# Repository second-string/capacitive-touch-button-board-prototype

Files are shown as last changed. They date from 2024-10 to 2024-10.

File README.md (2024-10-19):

# capacitive-touch-button-board-prototype

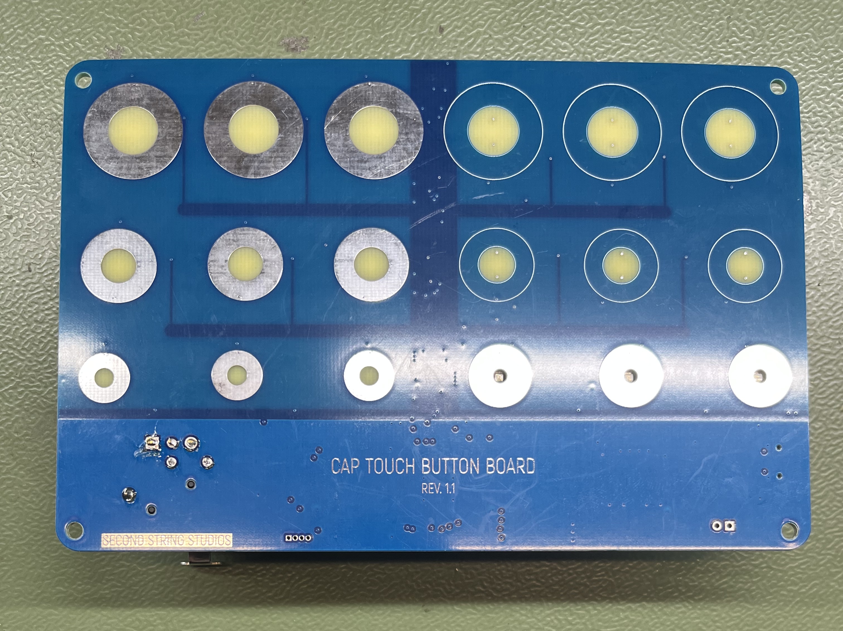
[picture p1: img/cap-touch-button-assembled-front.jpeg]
Version 1.1 of the capacitive touch button test board front

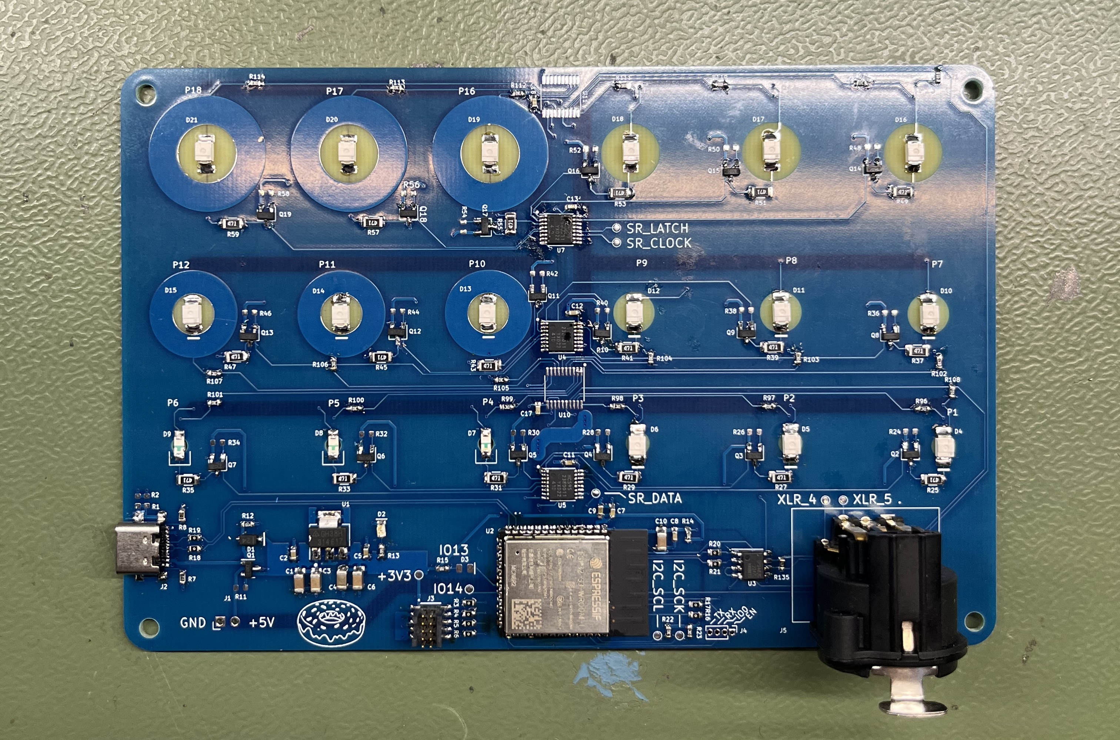
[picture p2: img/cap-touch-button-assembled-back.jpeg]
Version 1.1 of the capacitive touch button test board back


This repo contains two designs for prototype PCBs for testing different capacitive touch button styles and different reverse-mounted LED colors and styles. While version 1.1 was indeed fabbed, built, and works, these files are made public only for reference. **Do not expect to build these designs with no changes and have everything working for you**.

Version 1.0 is the full 6x6 version of the board. It all fabrication outputs were generated, but the board was never fabbed due to cost.
Version 1.1 is the same as 1.0 but with the top 3 rows of buttons removed to simplify the design physical size and part cost.   

There is a schematic PDF and PCB layer prints PDF in the version 1.1 directory if you do not have KiCad. Version 1.1 that was built also contains generated Excel and interactive boms in its main directory or the `bom/` directory.

Find the custom capacitive touch footprints in the `symbols_and_footprints/` directory of each hardware version.

There is test firmware for version 1.1 in `button-board_rev_1_1/bringup_firmware/`. **NOTE:** This firmware is sloppy, terribly written, inefficient, and everything is hardcoded. It is only included as a reference, do not think that this will work for you out of the box.

Videos of example behavior are in the `img/` directory.

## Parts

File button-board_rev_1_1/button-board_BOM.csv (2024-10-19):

Reference | Value | Footprint | Link | MPN | Menge
C1, C3, C6, C10 | 10uF | Capacitor_SMD:C_1206_3216Metric | https://www.digikey.de/en/products/detail/samsung-electro-mechanics/CL31B106KOHNNWE/3888763 | CL31B106KOHNNWE | 4
C2, C5, C9 | 1uF | Capacitor_SMD:C_0603_1608Metric | https://www.digikey.de/en/products/detail/samsung-electro-mechanics/CL10A105KA8NNNC/3886760 | CL10A105KA8NNNC | 3
C4 | 22uF | Capacitor_SMD:C_1206_3216Metric | https://www.digikey.de/en/products/detail/samsung-electro-mechanics/CL31A226MOCLNNC/3888386 | CL31A226MOCLNNC | 1
C7, C8, C11-C13, C17, C18 | 0.1uF | Capacitor_SMD:C_0603_1608Metric | https://www.digikey.de/en/products/detail/kyocera-avx/KGM15BR71H104KT/1600046 | KYOCERA AVX | 7
D1 | D | Diode_SMD:D_SOD-123F | https://www.digikey.de/en/products/detail/good-ark-semiconductor/FS24/18667767 | FS24 | 1
D2, D3 | LED | Diode_SMD:D_0805_2012Metric |  |  | 2
D4-D6, D10-D12, D16-D21 | LED | LED_SMD:LED_SunLED_XZ_Reverse_Mount |  |  | 12
D7-D9 | LED | LTST-C230K:LED_LTST-C230K |  |  | 3
D13-D15 | LED | LED_SMD:LED_SunLED_XZ_Reverse_Mount_Cut_Pads |  |  | 3
H1-H4 | MountingHole | MountingHole:MountingHole_3.2mm_M3 |  |  | 4
J1 | Screw_Terminal_01x02 | Connector_PinHeader_2.54mm:PinHeader_1x02_P2.54mm_Horizontal |  |  | 1
J2 | USB_C_Receptacle_USB2.0_EDITED | GSB1C41110SSHR:AMPHENOL_GSB1C41110SSHR | https://www.digikey.de/en/products/detail/amphenol-cs-commercial-products/GSB1C41110SSHR/21623839 | GSB1C41110SSHR | 1
J3 | FTSH-105-01-S-DV-TR | FTSH-105-01-S-DV-TR:SAMTEC_FTSH-105-01-S-DV-TR | https://www.digikey.de/en/products/detail/samtec-inc/FTSH-105-01-S-DV-TR/7432340 | FTSH-105-01-S-DV-TR | 1
J4 | Conn_01x04 | Connector_PinHeader_1.27mm:PinHeader_1x04_P1.27mm_Vertical |  |  | 1
J5 | XLR5_Ground | NC5FAH:NEUTRIK_NC5FAH | https://www.digikey.de/en/products/detail/amphenol-sine-systems-corp/AC5FAV-AU-B/10443110 | AC5FAV-AU-B | 1
P1-P3 | ~ | Button_Switch_SMD:Cap_Touch_Ring_Small |  |  | 3
P4-P6 | ~ | Button_Switch_SMD:Cap_Touch_Ring_Cutout |  |  | 3
P7-P9 | ~ | Button_Switch_SMD:Cap_Touch_Ring_Medium |  |  | 3
P10-P12 | ~ | Button_Switch_SMD:Cap_Touch_Ring_Medium_Bottom |  |  | 3
P13-P15 | ~ | Button_Switch_SMD:Cap_Touch_Ring_Large |  |  | 3
P16-P18 | ~ | Button_Switch_SMD:Cap_Touch_Ring_Large_Bottom |  |  | 3
Q1 | PMOS | Package_TO_SOT_SMD:SOT-23 | https://www.digikey.de/en/products/detail/good-ark-semiconductor/GSF2301/18667474 | GSF2301 | 1
Q2-Q19 | NMOS | Package_TO_SOT_SMD:TSOT-23 | https://www.digikey.de/en/products/detail/anbon-semiconductor-int-l-limited/AS2302/16708469 | AS2302 | 18
R1-R6, R11, R16-R21 | 0R | Resistor_SMD:R_0603_1608Metric |  |  | 13
R7, R8 | 5k1 | Resistor_SMD:R_0603_1608Metric | https://www.digikey.de/en/products/detail/yageo/RT0603DRD075K1L/1035586 | RT0603DRD075K1L | 2
R12 | 100k | Resistor_SMD:R_0603_1608Metric | https://www.digikey.de/en/products/detail/yageo/RC0603FR-0747KL/727253 | RC0603FR-0747KL | 1
R13, R15 | 3.3k-8k | Resistor_SMD:R_0603_1608Metric | https://www.digikey.de/en/products/detail/yageo/RC0603JR-076K8L/726813 | RC0603JR-076K8L | 2
R14, R22-R24, R26, R28, R30, R32, R34, R36, R38, R40, R42, R44, R46, R48, R50, R52, R54, R56, R58, R96-R107, R109-R114 | 10k | Resistor_SMD:R_0603_1608Metric | https://www.digikey.de/en/products/detail/yageo/RC0603FR-0710KL/726880 | RC0603FR-0710KL | 39
R25, R27, R29, R31, R33, R35, R37, R39, R41, R43, R45, R47, R49, R51, R53, R55, R57, R59 | 470R 1/2W | Resistor_SMD:R_1206_3216Metric | https://www.digikey.de/en/products/detail/panasonic-electronic-components/ERJ-P08J471V/525396 | ERJ-P08J471V | 18
R108, R121 | 47k | Resistor_SMD:R_0603_1608Metric | https://www.digikey.de/en/products/detail/yageo/RC0603FR-0747KL/727253 | RC0603FR-0747KL | 2
R135 | 120R | Resistor_SMD:R_0603_1608Metric | https://www.digikey.de/en/products/detail/stackpole-electronics-inc/RMCF0603FT120R/1761221 | RMCF0603FT120R | 1
TP1, TP2 | TestPoint | TestPoint:TestPoint_Pad_D1.0mm |  |  | 2
TP3 | 3V3 | TestPoint:TestPoint_Pad_D1.0mm |  |  | 1
TP4 | IO14 | TestPoint:TestPoint_Pad_D1.0mm |  |  | 1
TP5 | LATCH | TestPoint:TestPoint_Pad_D1.0mm |  |  | 1
TP6 | CLOCK | TestPoint:TestPoint_Pad_D1.0mm |  |  | 1
TP7 | DATA | TestPoint:TestPoint_Pad_D1.0mm |  |  | 1
TP8 | SCL | TestPoint:TestPoint_Pad_D1.0mm |  |  | 1
TP9 | SCK | TestPoint:TestPoint_Pad_D1.0mm |  |  | 1
U1 | AZ1117CH2-3.3 | Package_TO_SOT_SMD:SOT-223 | https://www.digikey.de/en/products/detail/diodes-incorporated/AZ1117CH2-3-3TRG1/7352815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 | AZ1117CH2-3.3TRG1 | 1
U2 | ESP32-S3-WROOM-1 | PCM_Espressif:ESP32-S3-WROOM-1 | https://www.digikey.de/en/products/detail/espressif-systems/ESP32-S3-WROOM-1-N8R2/15200058 | ESP32-S3-WROOM-1-N8R2 | 1
U3 | SP3485CN | Package_SO:SOIC-8_3.9x4.9mm_P1.27mm | https://www.digikey.de/en/products/detail/maxlinear-inc/SP3485CN-L/2411076 | SP3485CN-L | 1
U4, U5, U7 | 74HC595 | Package_SO:TSSOP-16_4.4x5mm_P0.65mm | https://www.digikey.de/en/products/detail/nexperia-usa-inc/74HC595PW-118/946653 | 74HC595PW,118 | 3
U10, U11 | AT42QT2120-SU | Package_SO:TSSOP-20_4.4x6.5mm_P0.65mm | https://www.digikey.de/en/products/detail/microchip-technology/AT42QT2120-SU/3678689 | AT42QT2120-SU | 2

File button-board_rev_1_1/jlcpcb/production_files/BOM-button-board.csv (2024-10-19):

Comment | Designator | Footprint | LCSC
XLR5_Ground | J5 | NEUTRIK_NC5FAH
LED | D15 | LED_SunLED_XZ_Reverse_Mount_Cut_Pads
LED | D14 | LED_SunLED_XZ_Reverse_Mount_Cut_Pads
LED | D13 | LED_SunLED_XZ_Reverse_Mount_Cut_Pads
LED | D12 | LED_SunLED_XZ_Reverse_Mount
LED | D11 | LED_SunLED_XZ_Reverse_Mount
LED | D10 | LED_SunLED_XZ_Reverse_Mount
~ | P17 | Cap_Touch_Ring_Large_Bottom
~ | P16 | Cap_Touch_Ring_Large_Bottom
~ | P9 | Cap_Touch_Ring_Medium
~ | P13 | Cap_Touch_Ring_Large
~ | P7 | Cap_Touch_Ring_Medium
~ | P5 | Cap_Touch_Ring_Cutout
MountingHole | H1 | MountingHole_3.2mm_M3
MountingHole | H2 | MountingHole_3.2mm_M3
~ | P11 | Cap_Touch_Ring_Medium_Bottom
~ | P14 | Cap_Touch_Ring_Large
~ | P12 | Cap_Touch_Ring_Medium_Bottom
MountingHole | H3 | MountingHole_3.2mm_M3
~ | P6 | Cap_Touch_Ring_Cutout
~ | P1 | Cap_Touch_Ring_Small
~ | P15 | Cap_Touch_Ring_Large
~ | P3 | Cap_Touch_Ring_Small
~ | P10 | Cap_Touch_Ring_Medium_Bottom
~ | P4 | Cap_Touch_Ring_Cutout
MountingHole | H4 | MountingHole_3.2mm_M3
~ | P2 | Cap_Touch_Ring_Small
~ | P8 | Cap_Touch_Ring_Medium
~ | P18 | Cap_Touch_Ring_Large_Bottom
0R | R16 | R_0603_1608Metric
470R 1/2W | R59 | R_1206_3216Metric
NMOS | Q8 | TSOT-23
1uF | C5 | C_0603_1608Metric
470R 1/2W | R25 | R_1206_3216Metric
SCL | TP8 | TestPoint_Pad_D1.0mm
10k | R113 | R_0603_1608Metric
470R 1/2W | R45 | R_1206_3216Metric
10uF | C10 | C_1206_3216Metric
470R 1/2W | R35 | R_1206_3216Metric
ESP32-S3-WROOM-1 | U2 | ESP32-S3-WROOM-1
NMOS | Q11 | TSOT-23
470R 1/2W | R41 | R_1206_3216Metric
47k | R108 | R_0603_1608Metric
R | R4 | R_0603_1608Metric
470R 1/2W | R57 | R_1206_3216Metric
100k | R12 | R_0603_1608Metric
NMOS | Q18 | TSOT-23
0.1uF | C17 | C_0603_1608Metric
AT42QT2120-SU | U11 | TSSOP-20_4.4x6.5mm_P0.65mm
AZ1117CH2-3.3 | U1 | SOT-223
10k | R112 | R_0603_1608Metric
NMOS | Q2 | TSOT-23
0.1uF | C8 | C_0603_1608Metric
0R | R18 | R_0603_1608Metric
74HC595 | U4 | TSSOP-16_4.4x5mm_P0.65mm
TestPoint | TP1 | TestPoint_Pad_D1.0mm
CLOCK | TP6 | TestPoint_Pad_D1.0mm
470R 1/2W | R37 | R_1206_3216Metric
0.1uF | C13 | C_0603_1608Metric
47k | R121 | R_0603_1608Metric
NMOS | Q9 | TSOT-23
R | R3 | R_0603_1608Metric
0R | R20 | R_0603_1608Metric
74HC595 | U7 | TSSOP-16_4.4x5mm_P0.65mm
SP3485CN | U3 | SOIC-8_3.9x4.9mm_P1.27mm
10k | R97 | R_0603_1608Metric
470R 1/2W | R39 | R_1206_3216Metric
470R 1/2W | R49 | R_1206_3216Metric
SCK | TP9 | TestPoint_Pad_D1.0mm
NMOS | Q19 | TSOT-23
470R 1/2W | R31 | R_1206_3216Metric
10k | R100 | R_0603_1608Metric
R | R5 | R_0603_1608Metric
LED | D4 | LED_SunLED_XZ_Reverse_Mount
10k | R105 | R_0603_1608Metric
3.3k-8k | R15 | R_0603_1608Metric
470R 1/2W | R55 | R_1206_3216Metric
470R 1/2W | R51 | R_1206_3216Metric
10k | R107 | R_0603_1608Metric
0R | R19 | R_0603_1608Metric
10k | R106 | R_0603_1608Metric
470R 1/2W | R43 | R_1206_3216Metric
IO14 | TP4 | TestPoint_Pad_D1.0mm
LATCH | TP5 | TestPoint_Pad_D1.0mm
TestPoint | TP2 | TestPoint_Pad_D1.0mm
NMOS | Q7 | TSOT-23
1uF | C9 | C_0603_1608Metric
120R | R135 | R_0603_1608Metric
22uF | C4 | C_1206_3216Metric
0.1uF | C11 | C_0603_1608Metric
10k | R101 | R_0603_1608Metric
PMOS | Q1 | SOT-23
10k | R110 | R_0603_1608Metric
LED | D19 | LED_SunLED_XZ_Reverse_Mount
0.1uF | C7 | C_0603_1608Metric
FTSH-105-01-S-DV-TR | J3 | SAMTEC_FTSH-105-01-S-DV-TR
5k1 | R7 | R_0603_1608Metric
10k | R111 | R_0603_1608Metric
10k | R102 | R_0603_1608Metric
0R | R17 | R_0603_1608Metric
NMOS | Q4 | TSOT-23
470R 1/2W | R27 | R_1206_3216Metric
DATA | TP7 | TestPoint_Pad_D1.0mm
NMOS | Q6 | TSOT-23
10k | R14 | R_0603_1608Metric
NMOS | Q12 | TSOT-23
NMOS | Q13 | TSOT-23
10k | R103 | R_0603_1608Metric
LED | D7 | LED_LTST-C230K
AT42QT2120-SU | U10 | TSSOP-20_4.4x6.5mm_P0.65mm
10k | R99 | R_0603_1608Metric
3V3 | TP3 | TestPoint_Pad_D1.0mm
LED | D21 | LED_SunLED_XZ_Reverse_Mount
LED | D18 | LED_SunLED_XZ_Reverse_Mount
1uF | C2 | C_0603_1608Metric
LED | D20 | LED_SunLED_XZ_Reverse_Mount
NMOS | Q15 | TSOT-23
LED | D3 | D_0805_2012Metric
470R 1/2W | R47 | R_1206_3216Metric
470R 1/2W | R53 | R_1206_3216Metric
10k | R114 | R_0603_1608Metric
10k | R22 | R_0603_1608Metric
10k | R104 | R_0603_1608Metric
10uF | C3 | C_1206_3216Metric
0.1uF | C18 | C_0603_1608Metric
10k | R23 | R_0603_1608Metric
0R | R21 | R_0603_1608Metric
10uF | C1 | C_1206_3216Metric
3.3k-8k | R13 | R_0603_1608Metric
LED | D9 | LED_LTST-C230K
NMOS | Q17 | TSOT-23
LED | D17 | LED_SunLED_XZ_Reverse_Mount
NMOS | Q14 | TSOT-23
USB_C_Receptacle_USB2.0_EDITED | J2 | AMPHENOL_GSB1C41110SSHR
10uF | C6 | C_1206_3216Metric
74HC595 | U5 | TSSOP-16_4.4x5mm_P0.65mm
Screw_Terminal_01x02 | J1 | PinHeader_1x02_P2.54mm_Horizontal
NMOS | Q10 | TSOT-23
LED | D2 | D_0805_2012Metric
NMOS | Q3 | TSOT-23
470R 1/2W | R33 | R_1206_3216Metric
10k | R109 | R_0603_1608Metric
R | R6 | R_0603_1608Metric
LED | D8 | LED_LTST-C230K
10k | R98 | R_0603_1608Metric
NMOS | Q5 | TSOT-23
D | D1 | D_SOD-123F
NMOS | Q16 | TSOT-23
LED | D6 | LED_SunLED_XZ_Reverse_Mount
470R 1/2W | R29 | R_1206_3216Metric
10k | R96 | R_0603_1608Metric
0.1uF | C12 | C_0603_1608Metric
LED | D5 | LED_SunLED_XZ_Reverse_Mount
5k1 | R8 | R_0603_1608Metric
Conn_01x04 | J4 | PinHeader_1x04_P1.27mm_Vertical
LED | D16 | LED_SunLED_XZ_Reverse_Mount

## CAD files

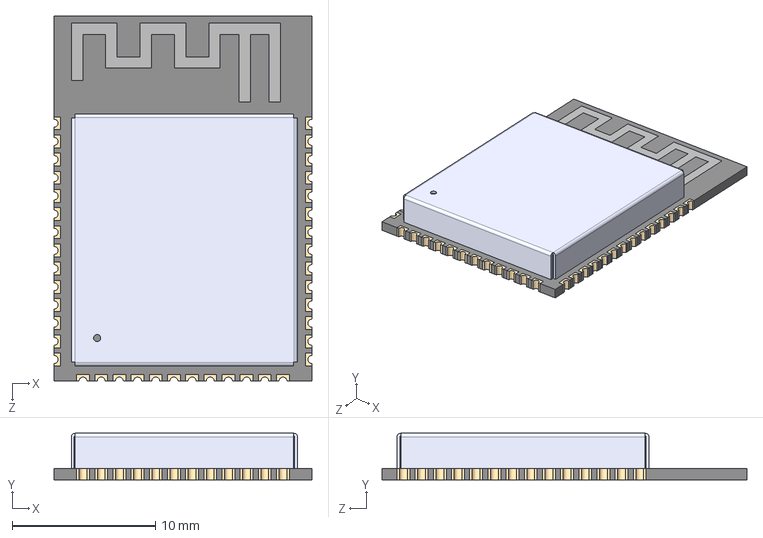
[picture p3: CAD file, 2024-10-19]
button-board_rev_1_1/symbols and footprints/ESP32-WROOM-S3/ESP32S3WROOM1N16R2.STEP
18.0 x 3.25 x 25.5 mm

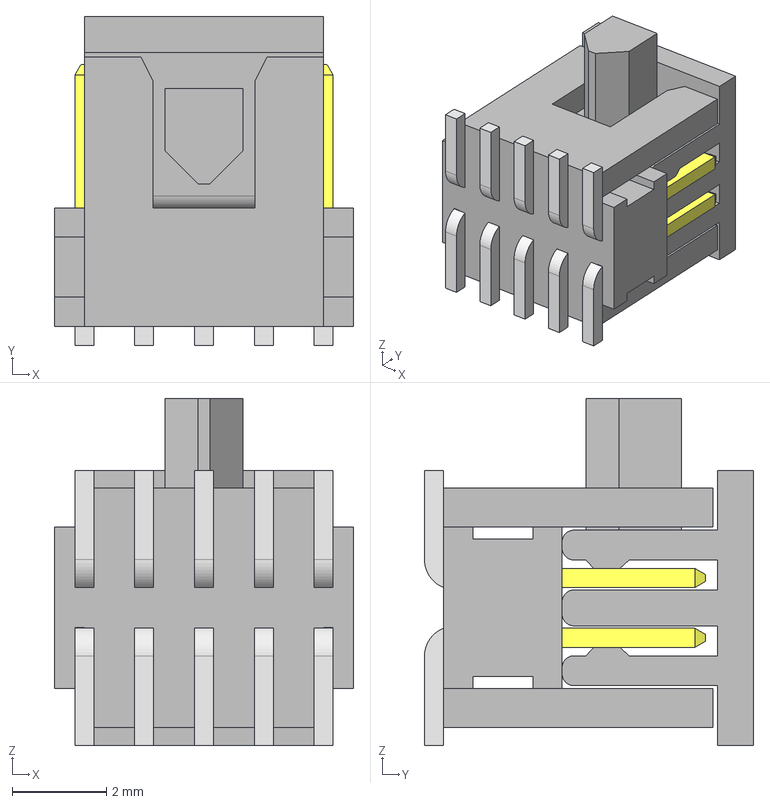
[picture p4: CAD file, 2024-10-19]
button-board_rev_1_1/symbols and footprints/FTSH-105-01-S-DV-TR/FTSH-105-01-S-DV-TR.step
6.35 x 6.98 x 7.37 mm
FTSH-105-01-S-DV-K-P-TR_body
FTSH-105-01-S-DV-K-P-TR_pins1
FTSH-105-01-S-DV-K-P-TR_pins2
FTSH-105-01-S-DV-K-P-TR_pp_pad

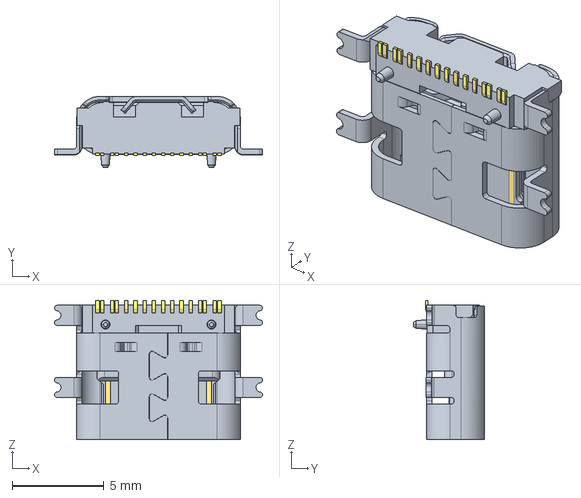
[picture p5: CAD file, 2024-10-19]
button-board_rev_1_1/symbols and footprints/GSB1C41110SSHR/GSB1C41110SSHR.step
11.3 x 3.89 x 7.60 mm

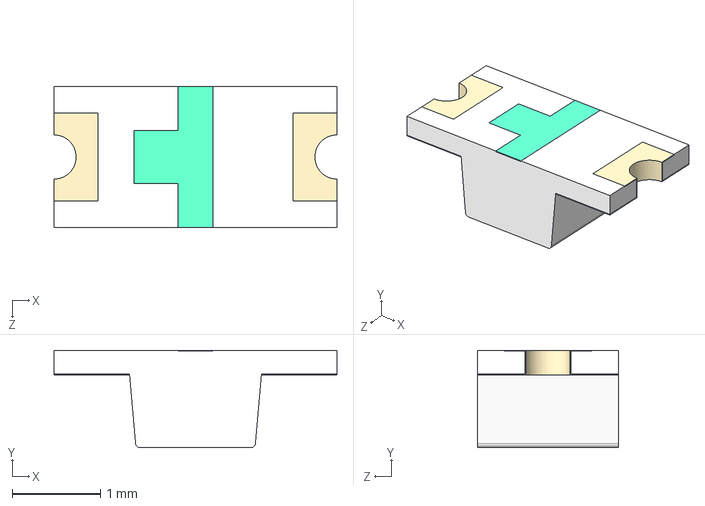
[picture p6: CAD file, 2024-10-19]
button-board_rev_1_1/symbols and footprints/LTST-C230K/LTST-C230K.step
3.20 x 1.10 x 1.60 mm

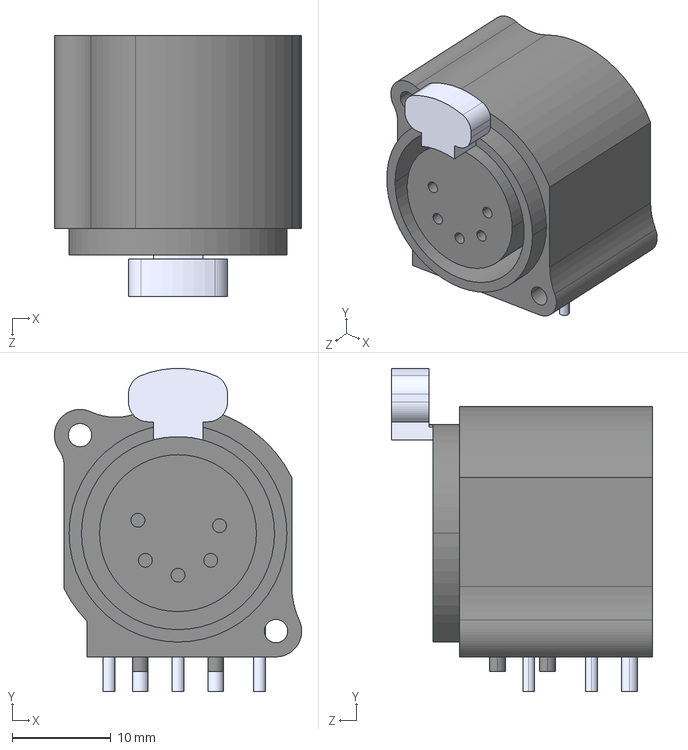
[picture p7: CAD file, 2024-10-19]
button-board_rev_1_1/symbols and footprints/NC5FAH/NC5FAH.step
25.0 x 32.6 x 26.4 mm

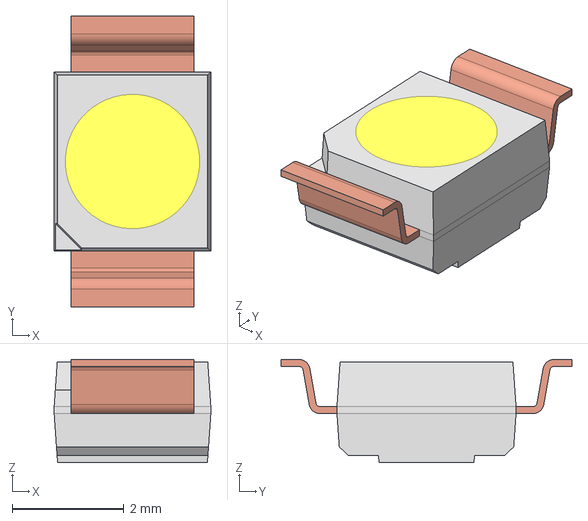
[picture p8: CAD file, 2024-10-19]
button-board_rev_1_1/symbols and footprints/XZxx45S/80472LED_SMD_PLCC-2_reverse_gullwing.stp
2.80 x 5.20 x 1.84 mm

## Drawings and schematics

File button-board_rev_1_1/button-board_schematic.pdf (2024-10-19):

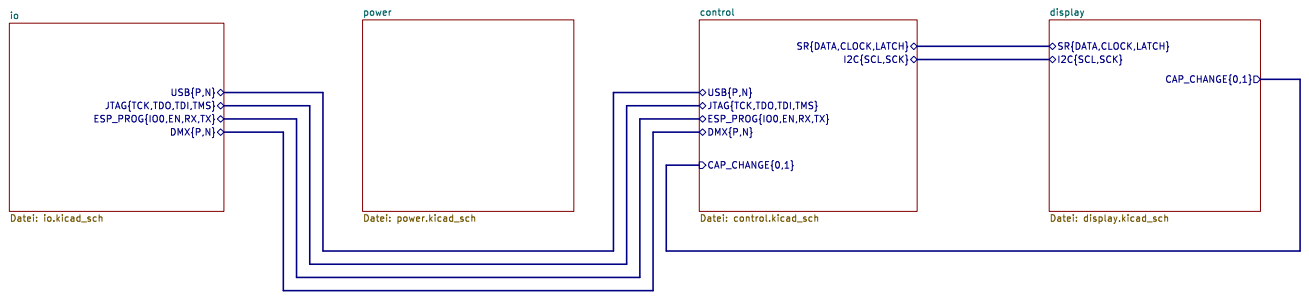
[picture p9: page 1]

SR{DATA,CLOCK,LATCH}

I2C{SCL,SCK}

USB{P,N}
JTAG{TCK,TDO,TDI,TMS}
ESP_PROG{IO0,EN,RX,TX}
DMX{P,N}

Id: 1/9 Title: File: button-board.kicad_sch Sheet: /

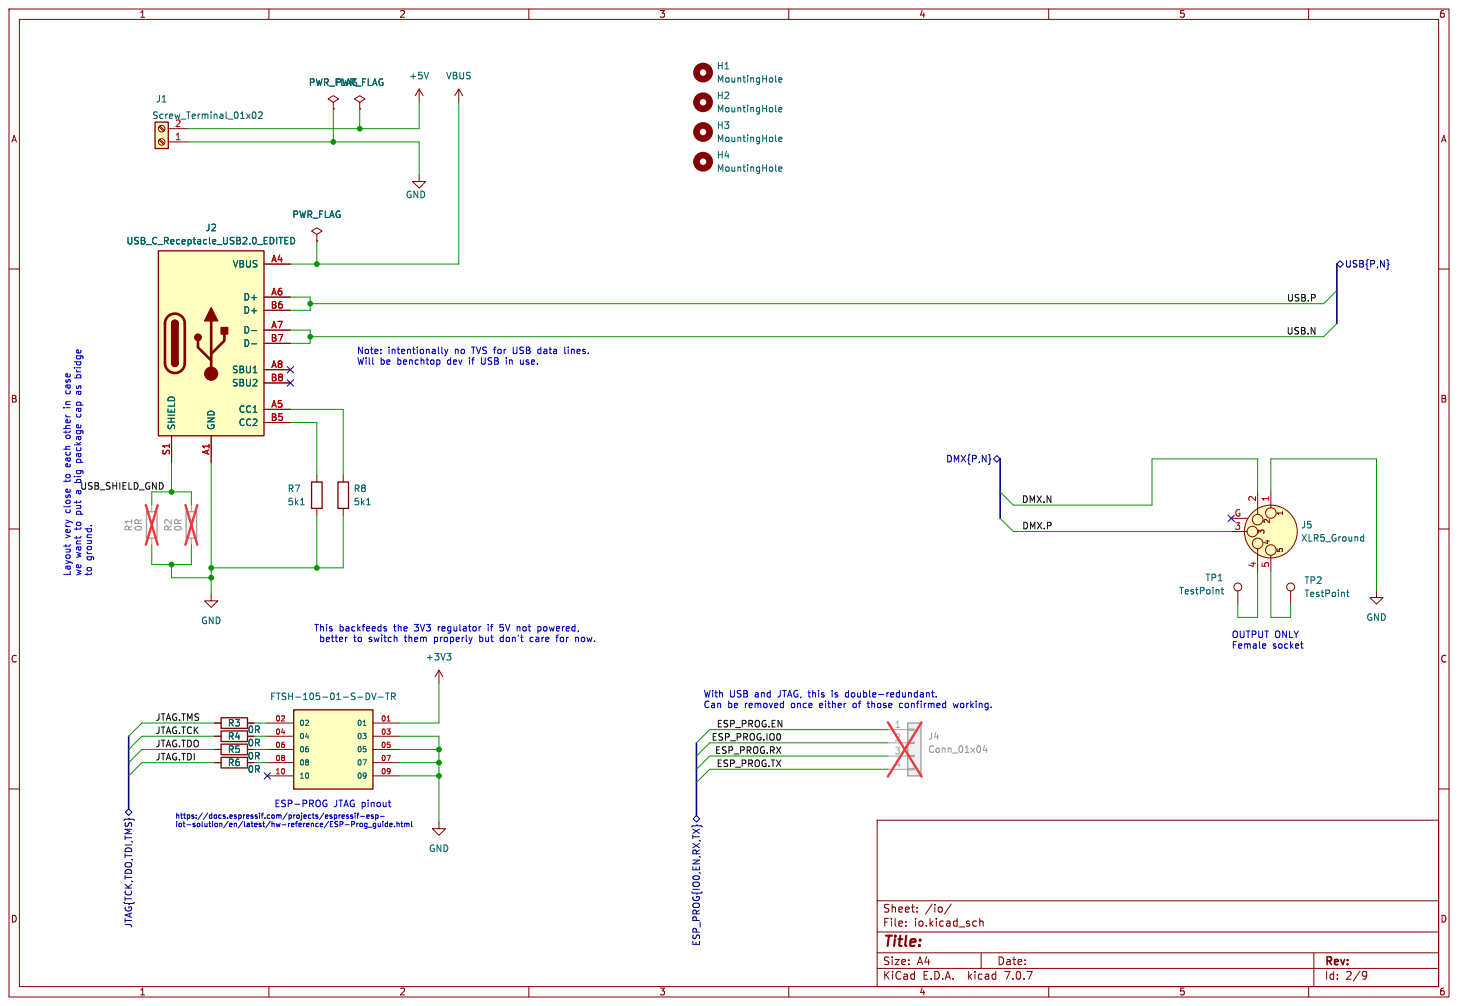
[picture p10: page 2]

USB{P,N} ESP_PROG{IO0,EN,RX,TX}

Id: 2/9 Title: File: io.kicad_sch Sheet: /io/

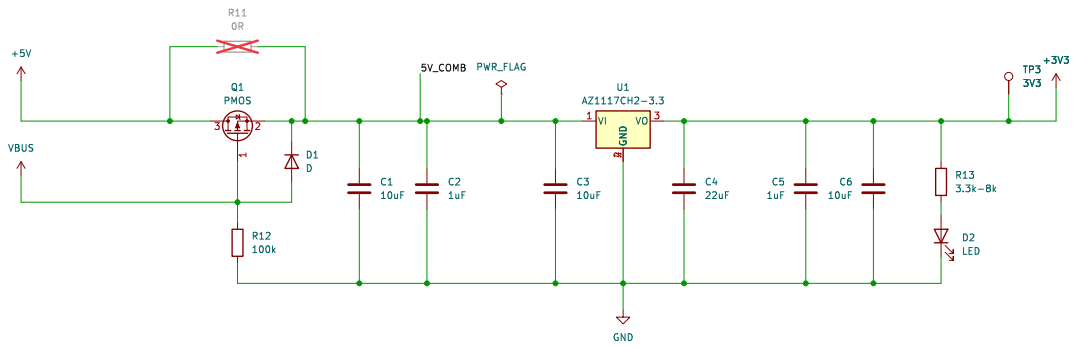
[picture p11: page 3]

Id: 3/9 Title: File: power.kicad_sch Sheet: /power/

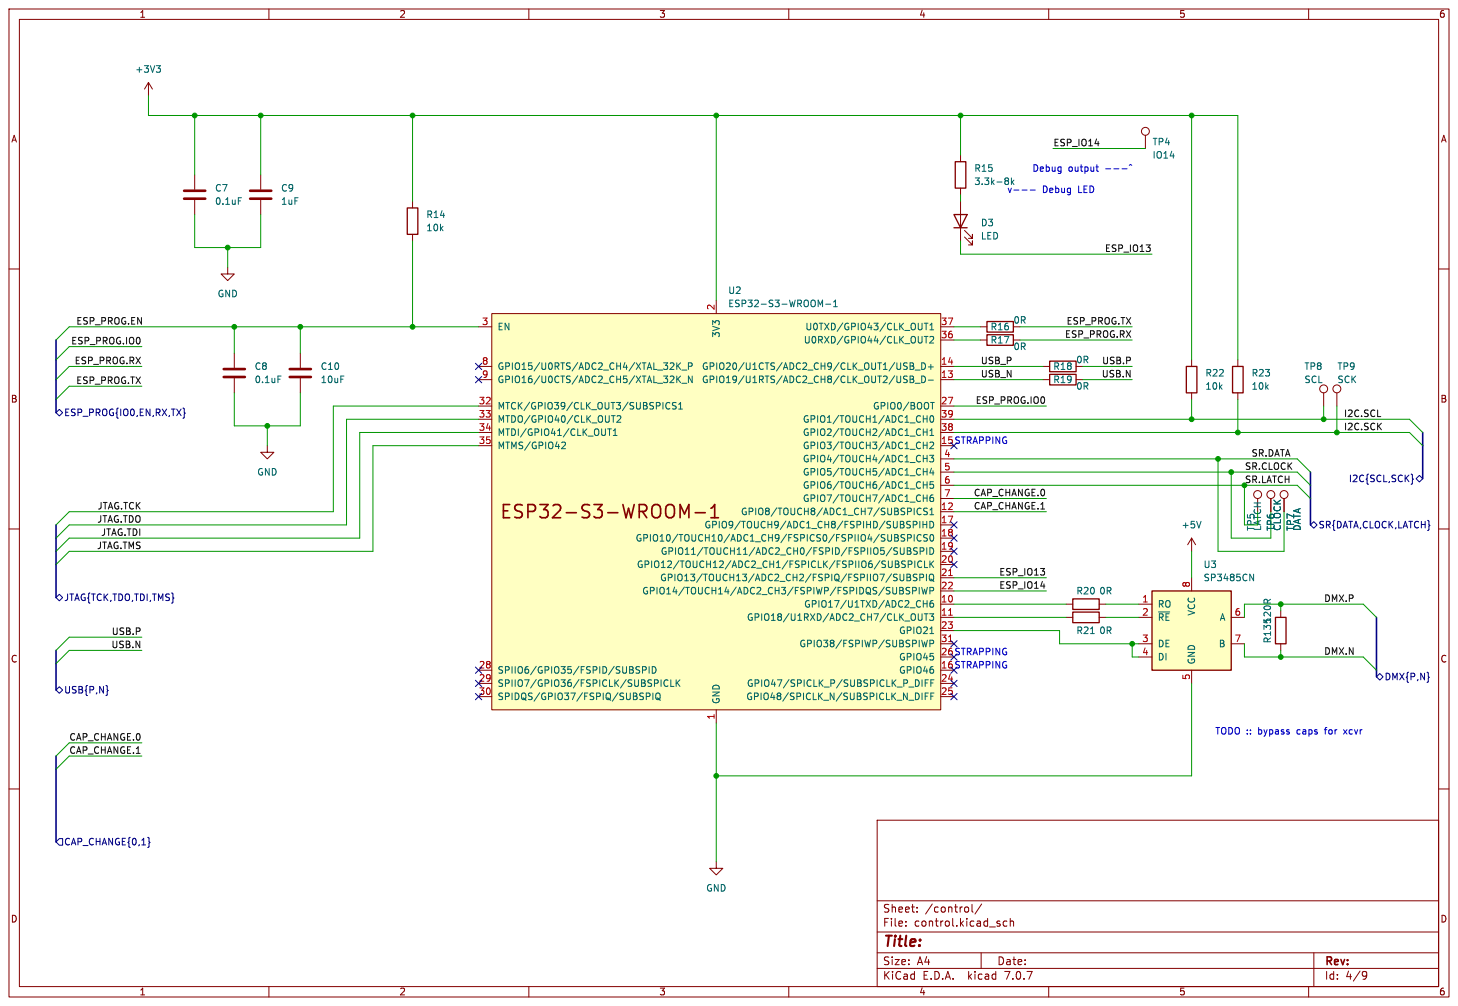
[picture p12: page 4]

2 GPIO12/TOUCH12/ADC2_CH1/FSPICLK/FSPIIO6/SUBSPICLK 20 GPIO13/TOUCH13/ADC2_CH2/FSPIQ/FSPIIO7/SUBSPIQ 21 GPIO14/TOUCH14/ADC2_CH3/FSPIWP/FSPIDQS/SUBSPIWP 22 GPIO21 23 GPIO47/SPICLK_P/SUBSPICLK_P_DIFF 24 GPIO48/SPICLK_N/SUBSPICLK_N_DIFF 25 GPIO45 26 GPIO0/BOOT 27 SPIIO6/GPIO35/FSPID/SUBSPID 28 SPIIO7/GPIO36/FSPICLK/SUBSPICLK 29 EN 3 SPIDQS/GPIO37/FSPIQ/SUBSPIQ 30 GPIO38/FSPIWP/SUBSPIWP 31 MTCK/GPIO39/CLK_OUT3/SUBSPICS1 32 MTDO/GPIO40/CLK_OUT2 33 MTDI/GPIO41/CLK_OUT1 34 MTMS/GPIO42 35 U0RXD/GPIO44/CLK_OUT2 36 U0TXD/GPIO43/CLK_OUT1 37 GPIO2/TOUCH2/ADC1_CH1 38 GPIO1/TOUCH1/ADC1_CH0 39 GPIO4/TOUCH4/ADC1_CH3 4 GPIO5/TOUCH5/ADC1_CH4 5 GPIO6/TOUCH6/ADC1_CH5 6 GPIO7/TOUCH7/ADC1_CH6 7 GPIO15/U0RTS/ADC2_CH4/XTAL_32K_P 8 GPIO16/U0CTS/ADC2_CH5/XTAL_32K_N 9 U2ESP32-S3-WROOM-1 R15

1 GPIO17/U1TXD/ADC2_CH6 10 GPIO18/U1RXD/ADC2_CH7/CLK_OUT3 11 GPIO8/TOUCH8/ADC1_CH7/SUBSPICS1 12 GPIO19/U1RTS/ADC2_CH8/CLK_OUT2/USB_D- 13 GPIO20/U1CTS/ADC2_CH9/CLK_OUT1/USB_D+ 14 GPIO3/TOUCH3/ADC1_CH2 15 GPIO46 16 GPIO9/TOUCH9/ADC1_CH8/FSPIHD/SUBSPIHD 17 GPIO10/TOUCH10/ADC1_CH9/FSPICS0/FSPIIO4/SUBSPICS0 18 GPIO11/TOUCH11/ADC2_CH0/FSPID/FSPIIO5/SUBSPID 19 3V3

TODO :: bypass caps for xcvr STRAPPING

SR{DATA,CLOCK,LATCH}

JTAG{TCK,TDO,TDI,TMS}

Id: 4/9 Title: File: control.kicad_sch Sheet: /control/

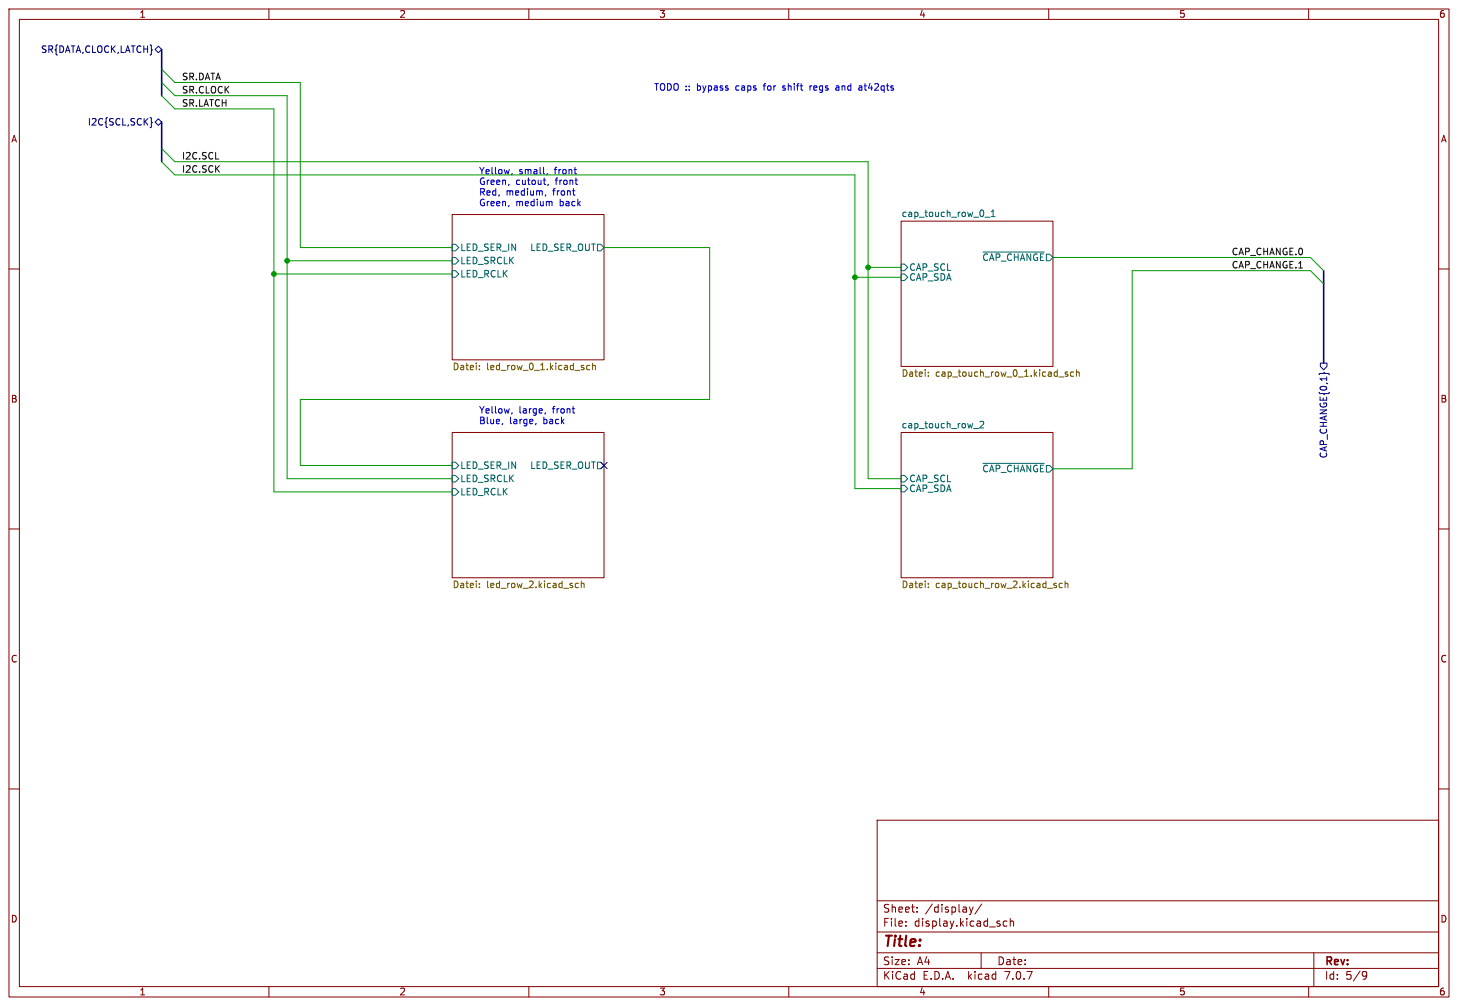
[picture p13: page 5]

TODO :: bypass caps for shift regs and at42qts Yellow, large, front Blue, large, back Yellow, small, front Green, cutout, front Red, medium, front Green, medium back

Id: 5/9 Title: File: display.kicad_sch Sheet: /display/

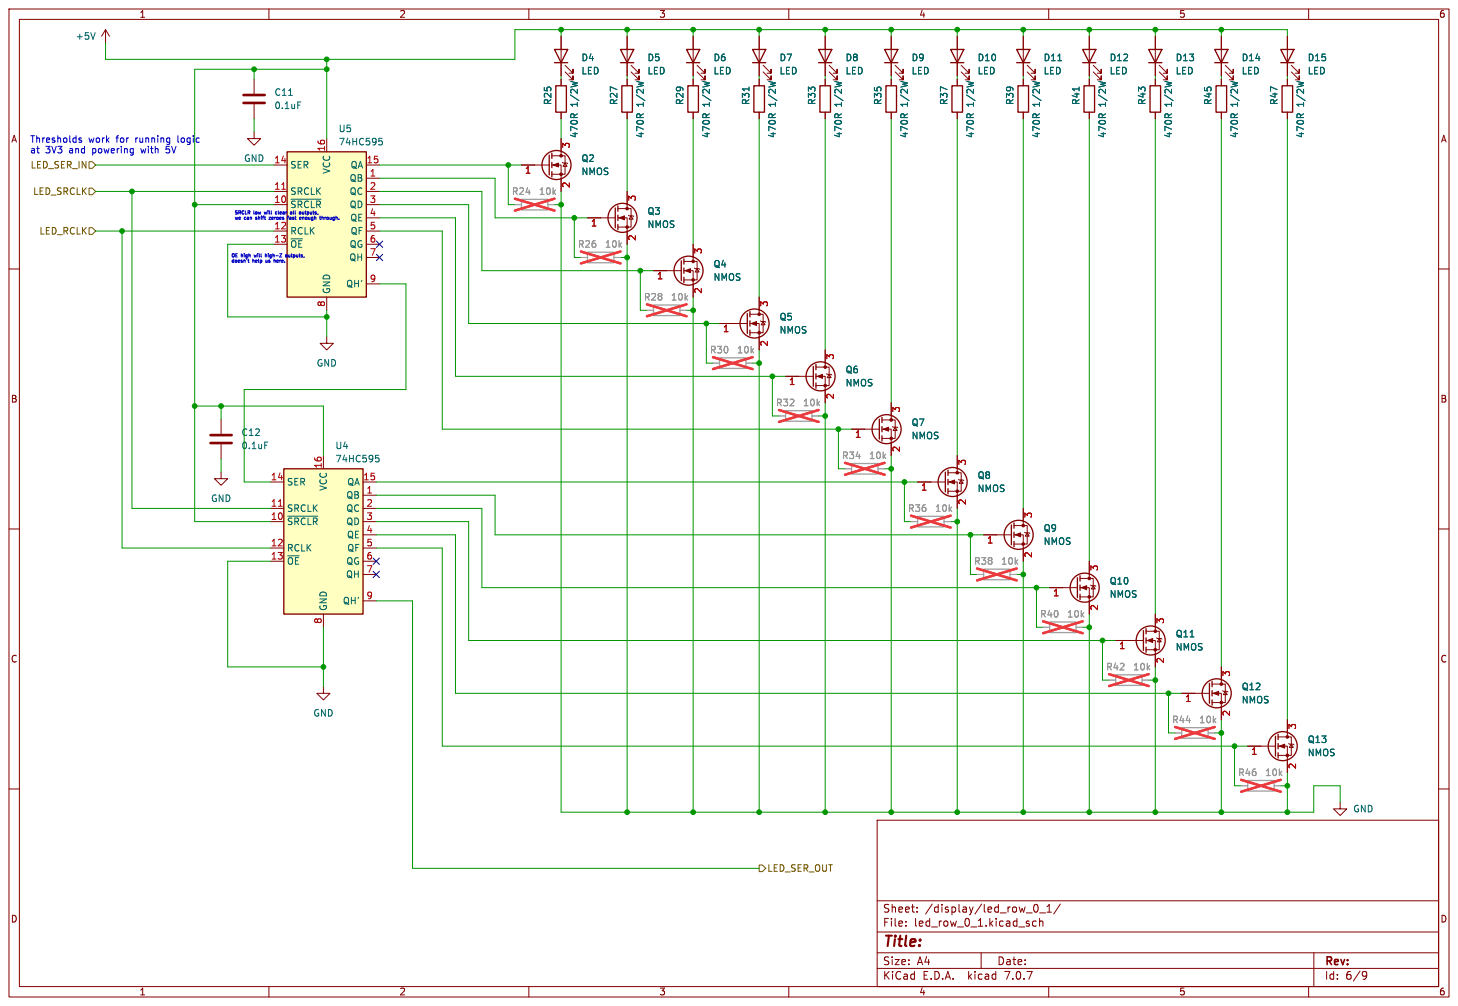
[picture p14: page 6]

Id: 6/9 Title: File: led_row_0_1.kicad_sch Sheet: /display/led_row_0_1/ R38 10k

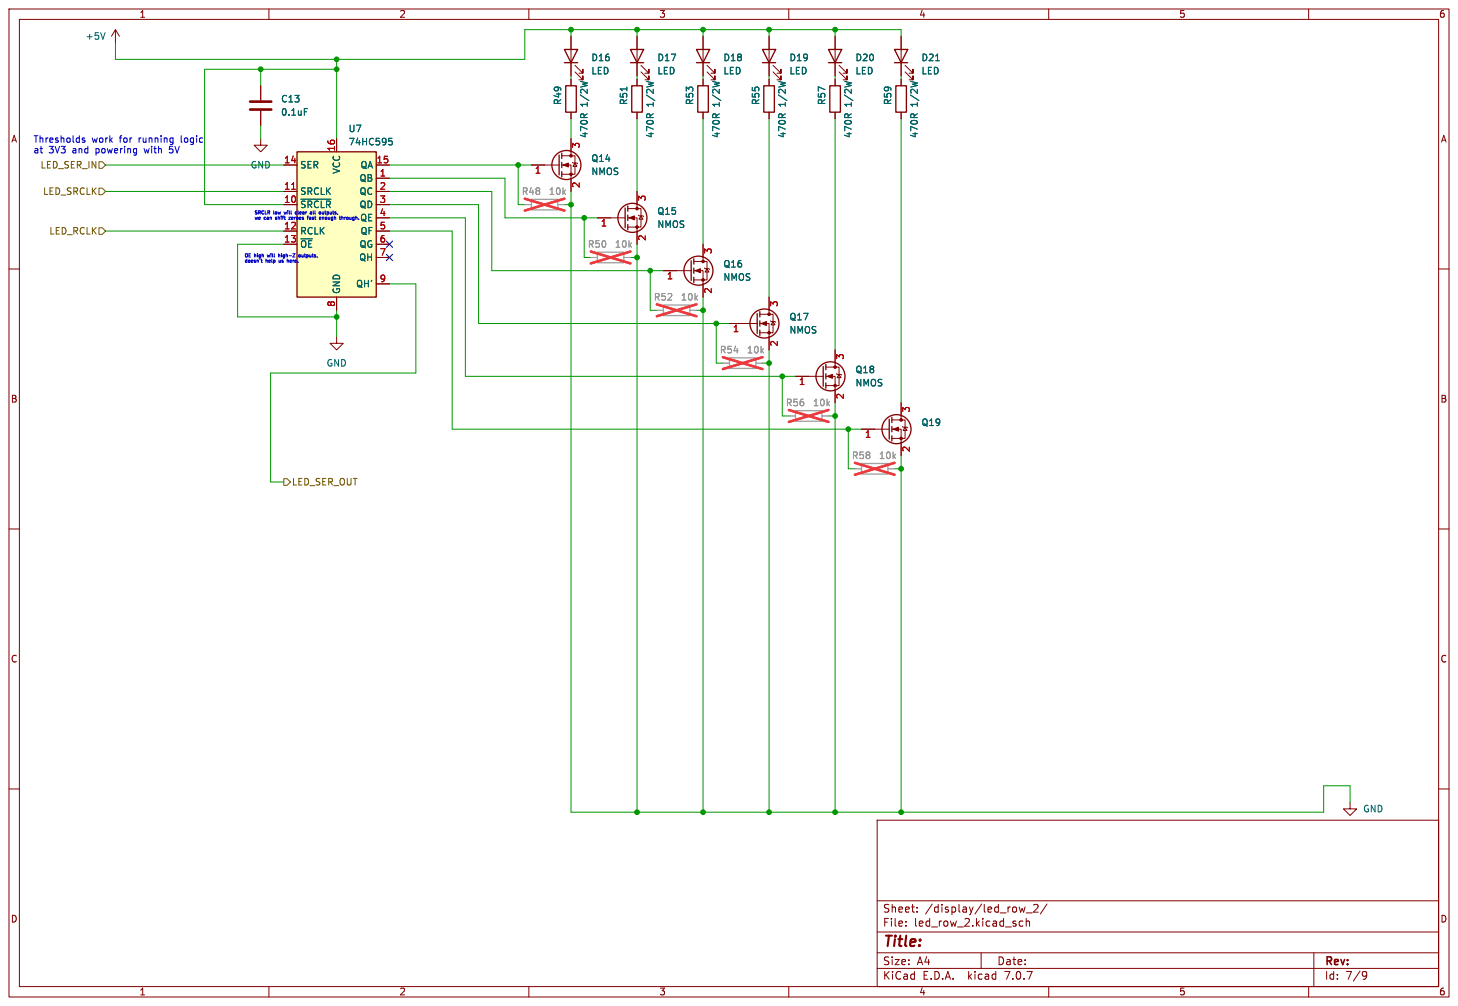
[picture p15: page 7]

Id: 7/9 Title: File: led_row_2.kicad_sch Sheet: /display/led_row_2/

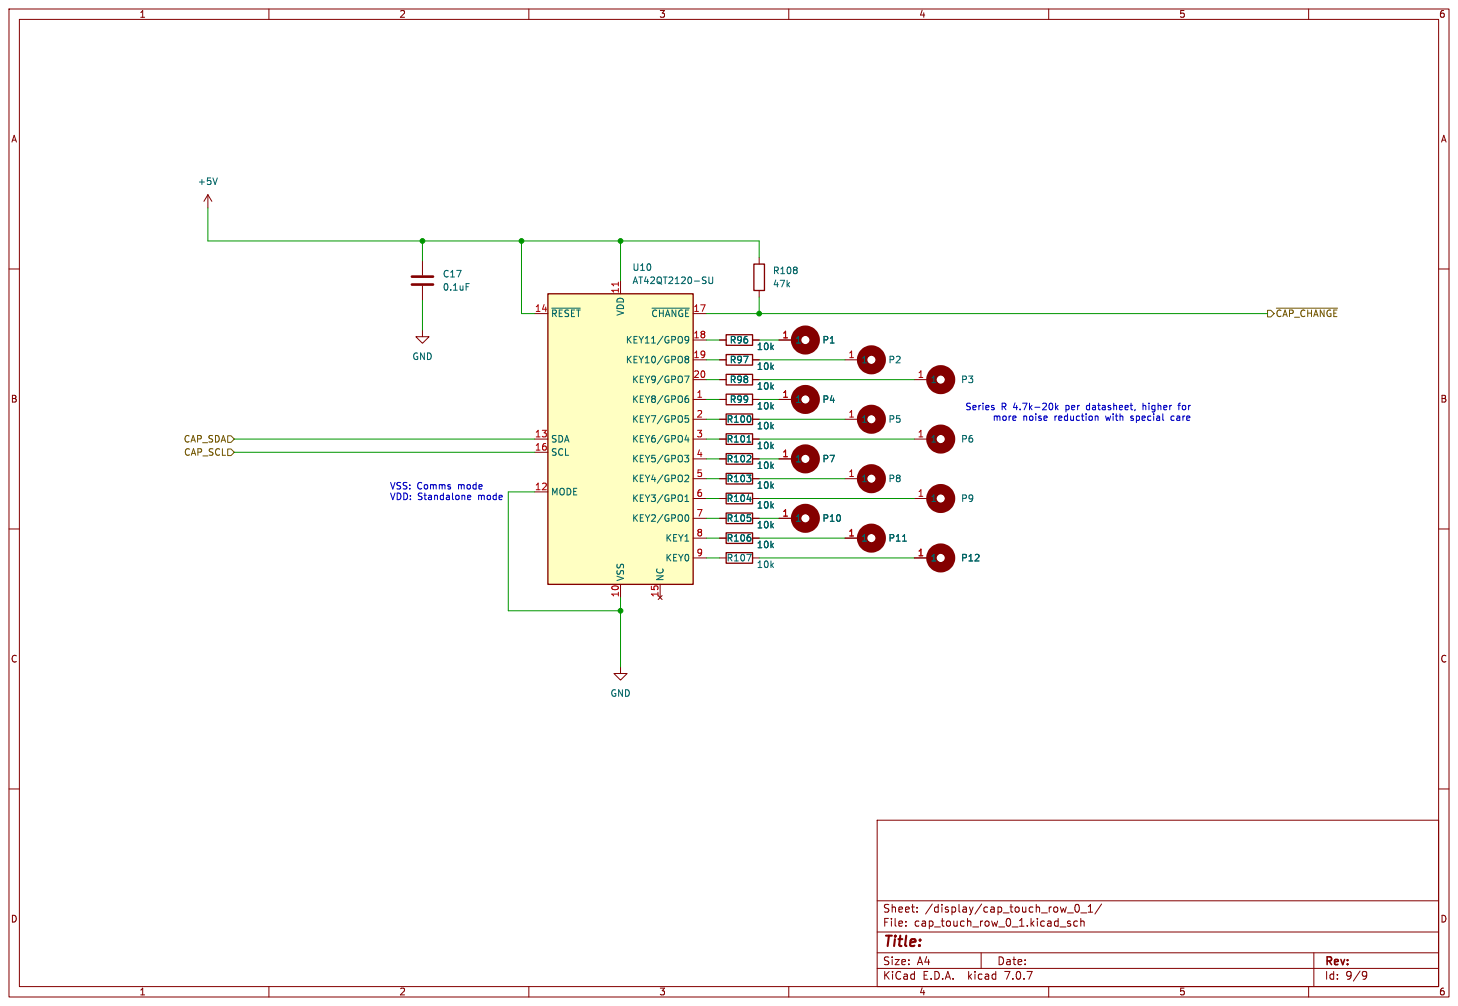
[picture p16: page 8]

Id: 9/9 Title: File: cap_touch_row_0_1.kicad_sch Sheet: /display/cap_touch_row_0_1/ GND

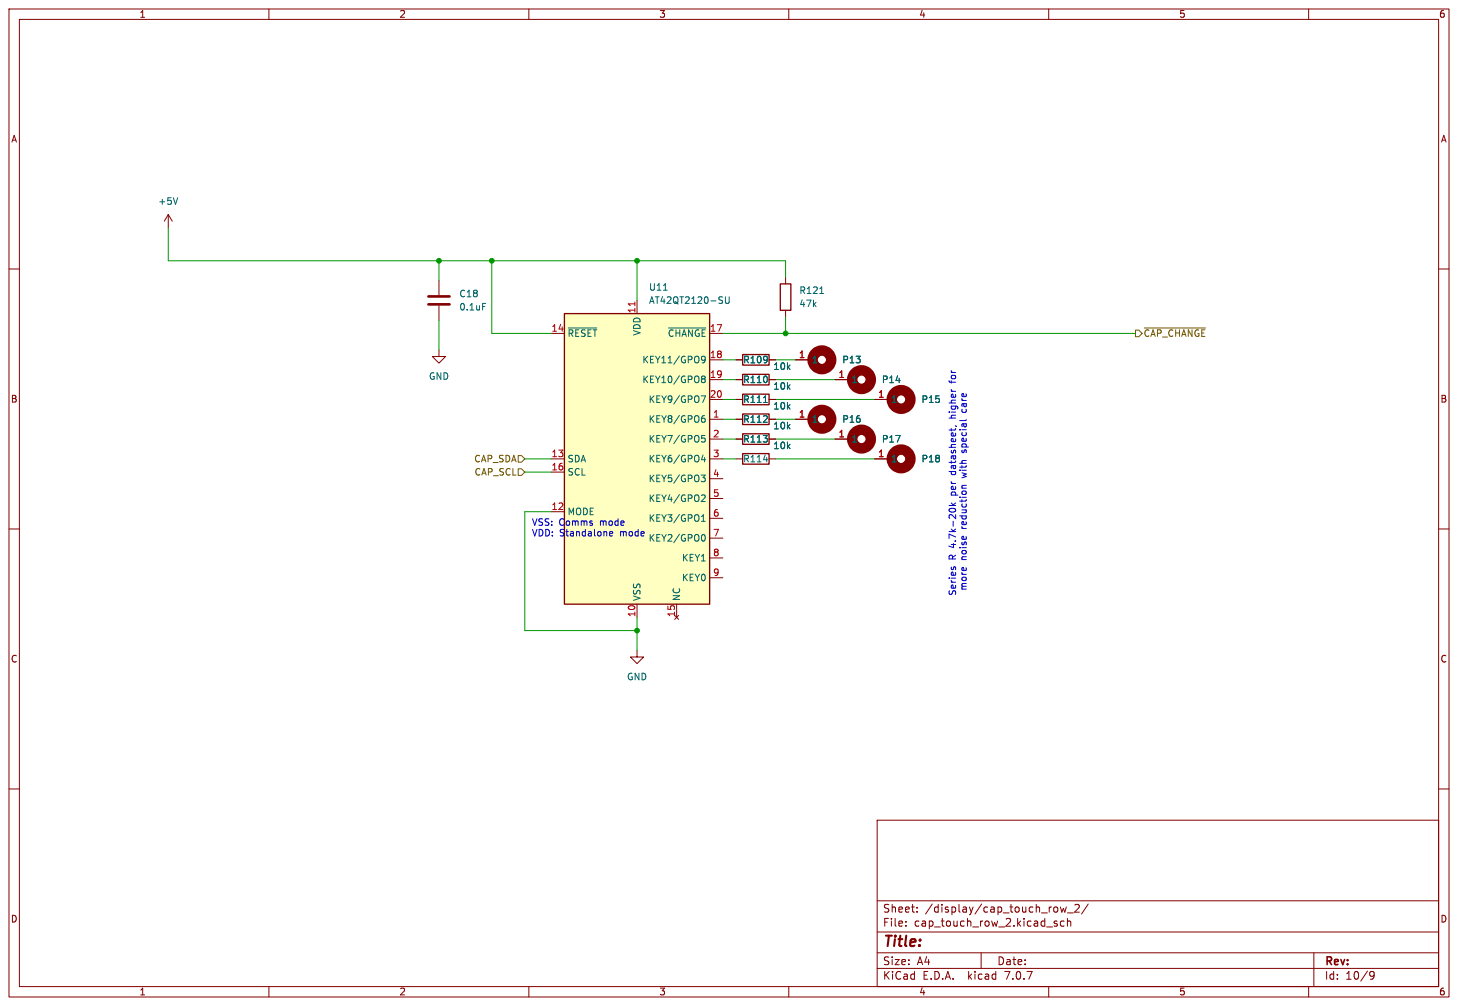
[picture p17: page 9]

Id: 10/9 Title: File: cap_touch_row_2.kicad_sch Sheet: /display/cap_touch_row_2/

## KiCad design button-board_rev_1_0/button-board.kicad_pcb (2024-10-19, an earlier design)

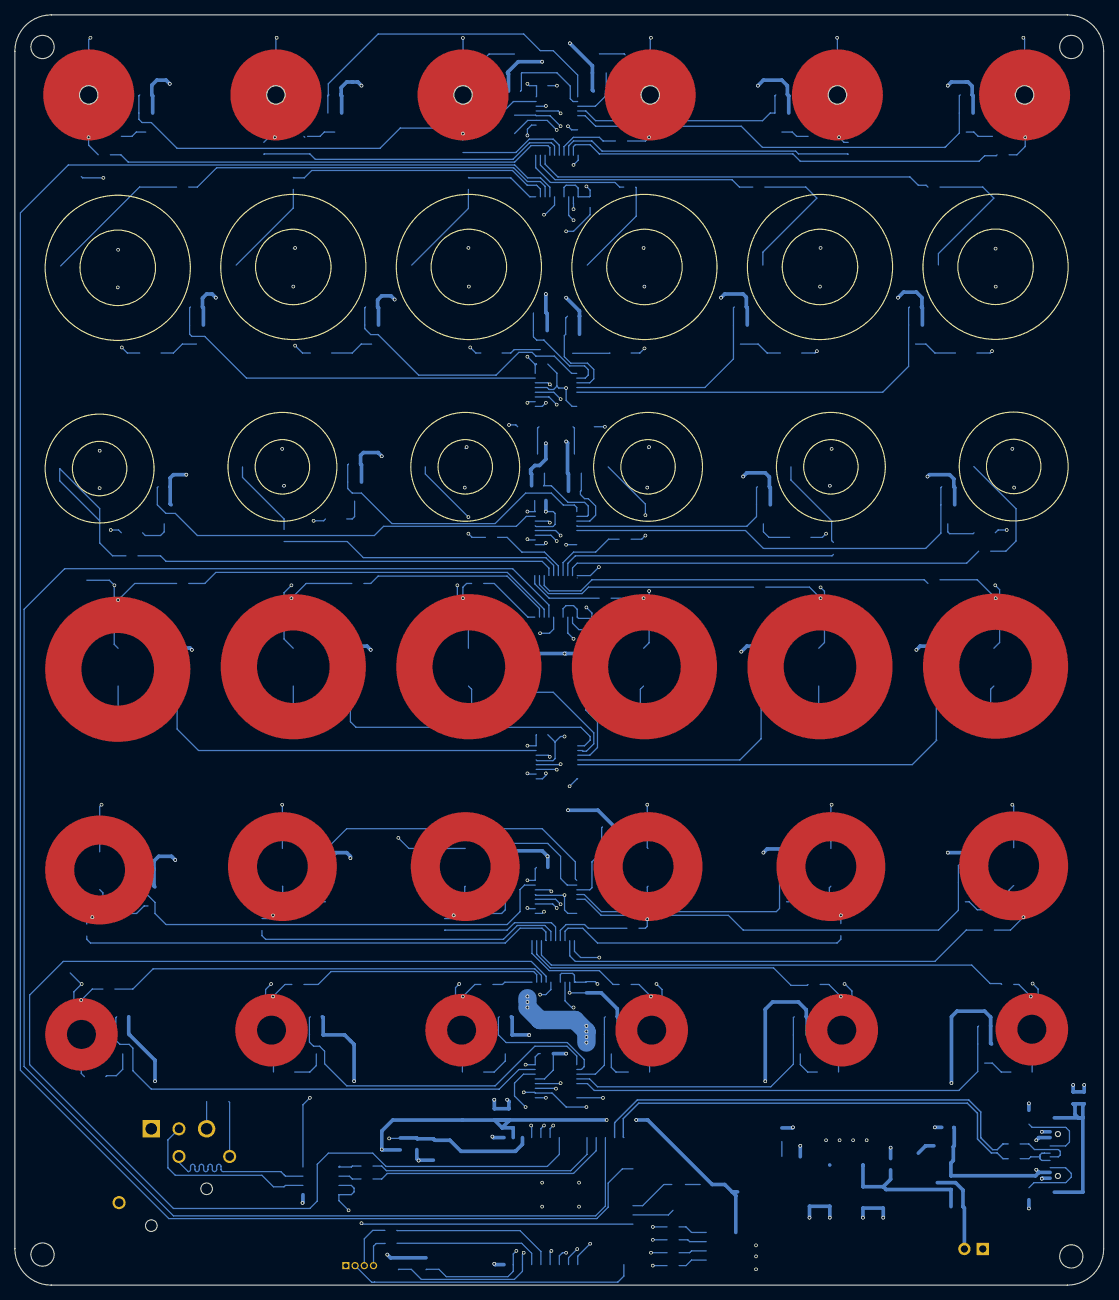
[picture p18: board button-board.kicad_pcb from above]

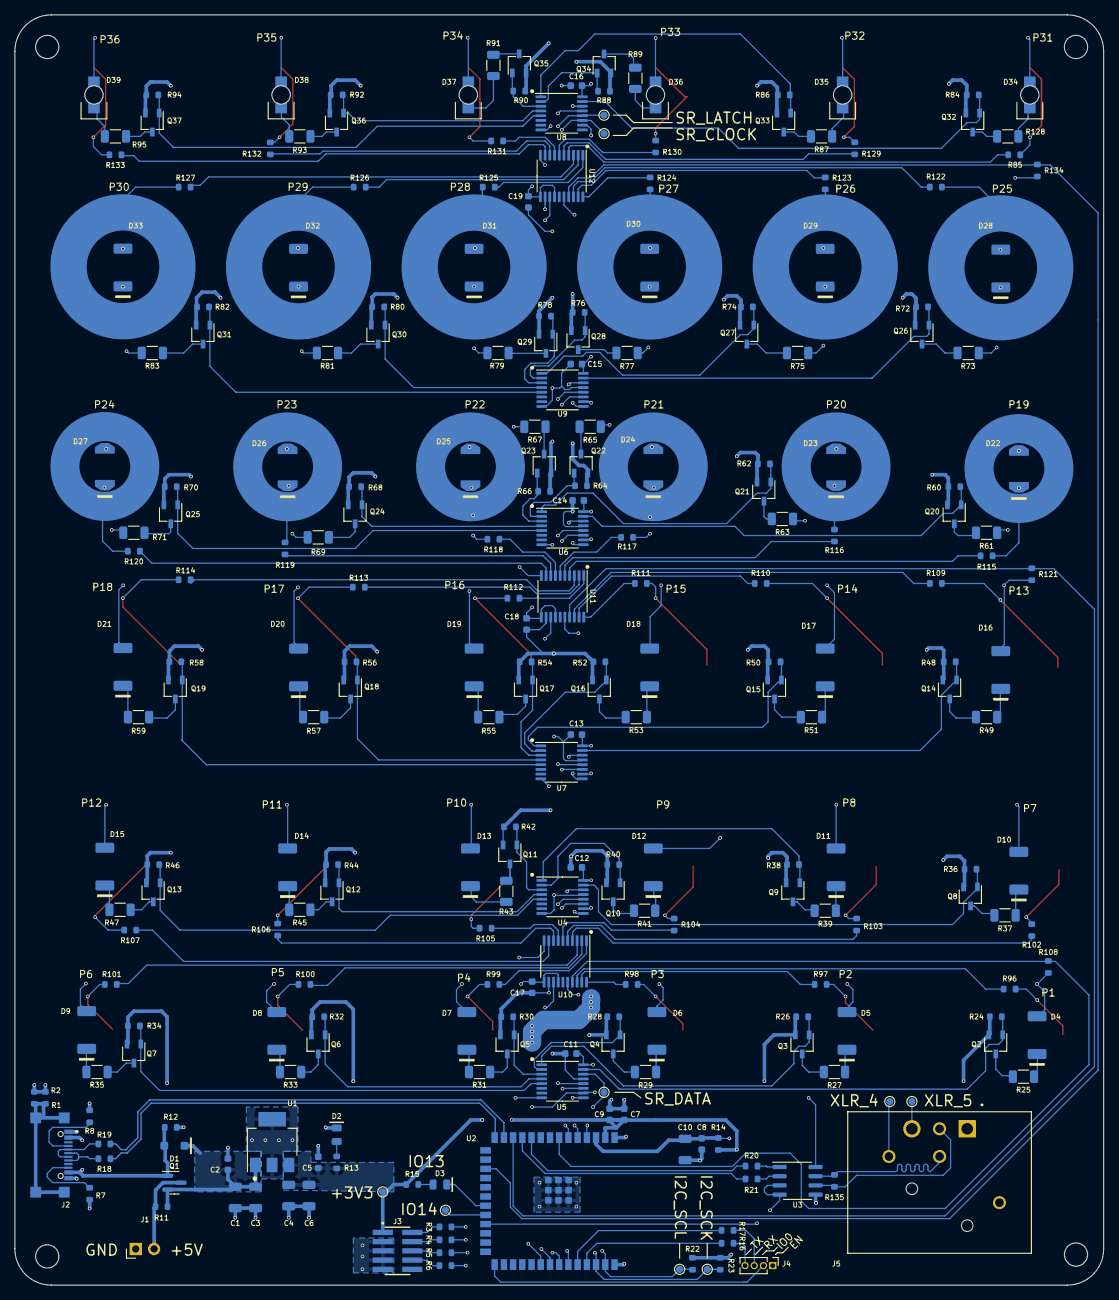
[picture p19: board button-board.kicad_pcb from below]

Board: 4 copper layers, 150.0 x 175.0 mm, 294 parts (254 on the bottom side), 232 nets.

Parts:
C1, C3, C6, C10: 10uF; C_1206_3216Metric
C2, C5, C9: 1uF; C_0603_1608Metric
C4: 22uF; C_1206_3216Metric
C7, C8, C11, C12, C13, C14, C15, C16, C17, C18, C19: 0.1uF; C_0603_1608Metric
D1: D; D_SOD-123F
D2, D3: LED; D_0805_2012Metric
D4, D5, D6, D7, D8, D9, D10, D11, D12, D13, D14, D15, D16, D17, D18, D19, D20, D21, D28, D29, D30, D31, D32, D33: LED; LED_SunLED_XZ_Reverse_Mount
D22, D23, D24, D25, D26, D27: LED; LED_SunLED_XZ_Reverse_Mount_Cut_Pads
D34, D35, D36, D37, D38, D39: LED; LED_LTST-C230K
H1, H2, H3, H4: MountingHole; MountingHole_3.2mm_M3
J1: Screw_Terminal_01x02; PinHeader_1x02_P2.54mm_Horizontal
J2: USB_C_Receptacle_USB2.0_EDITED; AMPHENOL_GSB1C41110SSHR
J3: FTSH-105-01-S-DV-TR; SAMTEC_FTSH-105-01-S-DV-TR
J4: Conn_01x04; PinHeader_1x04_P1.27mm_Vertical
J5: XLR5_Ground; NEUTRIK_NC5FAH
P1, P2, P3, P4, P5, P6: Cap_Touch_Ring_Small
P7, P8, P9, P10, P11, P12: Cap_Touch_Ring_Medium
P13, P14, P15, P16, P17, P18: Cap_Touch_Ring_Large
P19, P20, P21, P22, P23, P24: Cap_Touch_Ring_Medium_Bottom
P25, P26, P27, P28, P29, P30: Cap_Touch_Ring_Large_Bottom
P31, P32, P33, P34, P35, P36: Cap_Touch_Ring_Cutout
Q1: PMOS; SOT-23
Q2, Q3, Q4, Q5, Q6, Q7, Q8, Q9, Q10, Q11, Q12, Q13, Q14, Q15, Q16, Q17, Q18, Q19, Q20, Q21, Q22, Q23, Q24, Q25, Q26, Q27, Q28, Q29, Q30, Q31, Q32, Q33, Q34, Q35, Q36, Q37: NMOS; TSOT-23
R1, R2, R11, R16, R17, R18, R19, R20, R21: 0R; R_0603_1608Metric
R3, R4, R5, R6: R; R_0603_1608Metric
R7, R8: 5k1; R_0603_1608Metric
R12: 100k; R_0603_1608Metric
R13, R15: 3.3k-8k; R_0603_1608Metric
R14, R22, R23, R24, R26, R28, R30, R32, R34, R36, R38, R40, R42, R44, R46, R48, R50, R52, R54, R56, R58, R60, R62, R64, R66, R68, R70, R72, R74, R76, R78, R80, R82, R84, R86, R88, R90, R92, R94, R96, R97, R98, R99, R100, R101, R102, R103, R104, R105, R106, R107, R109, R110, R111, R112, R113, R114, R115, R116, R117, R118, R119, R120, R122, R123, R124, R125, R126, R127, R128, R129, R130, R131, R132, R133: 10k; R_0603_1608Metric
R25, R27, R29, R31, R33, R35, R37, R39, R41, R43, R45, R47, R49, R51, R53, R55, R57, R59, R61, R63, R65, R67, R69, R71, R73, R75, R77, R79, R81, R83, R85, R87, R89, R91, R93, R95: 470R 1/2W; R_1206_3216Metric
R108, R121, R134: 47k; R_0603_1608Metric
R135: 120R; R_0603_1608Metric
TP1, TP2: TestPoint; TestPoint_Pad_D1.0mm
TP3: 3V3; TestPoint_Pad_D1.0mm
TP4: IO14; TestPoint_Pad_D1.0mm
TP5: LATCH; TestPoint_Pad_D1.0mm
TP6: CLOCK; TestPoint_Pad_D1.0mm
TP7: DATA; TestPoint_Pad_D1.0mm
TP8: SCL; TestPoint_Pad_D1.0mm
TP9: SCK; TestPoint_Pad_D1.0mm
U1: AZ1117CH2-3.3; SOT-223
U2: ESP32-S3-WROOM-1
U3: SP3485CN; SOIC-8_3.9x4.9mm_P1.27mm
U4, U5, U6, U7, U8, U9: 74HC595; TSSOP-16_4.4x5mm_P0.65mm
U10, U11, U12: AT42QT2120-SU; TSSOP-20_4.4x6.5mm_P0.65mm

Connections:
+3V3: C4.1, C5.1, C6.1, C7.1, C9.1, J3.01, R13.1, R14.1, R15.1, R22.1, R23.1, TP3.1, U1.3 (VO), U2.2 (3V3)
+5V: C11.1, C12.1, C13.1, C14.1, C15.1, C16.1, C17.1, C18.1, C19.1, D4.2 (A), D5.2 (A), D6.2 (A), D7.2 (A), D8.2 (A), D9.2 (A), D10.2 (A), D11.2 (A), D12.2 (A), D13.2 (A), D14.2 (A), D15.2 (A), D16.2 (A), D17.2 (A), D18.2 (A), D19.2 (A), D20.2 (A), D21.2 (A), D22.2 (A), D23.2 (A), D24.2 (A), D25.2 (A), D26.2 (A), D27.2 (A), D28.2 (A), D29.2 (A), D30.2 (A), D31.2 (A), D32.2 (A), D33.2 (A), D34.2 (A), D35.2 (A), D36.2 (A), D37.2 (A), D38.2 (A), D39.2 (A), J1.2, Q1.3 (D), R11.1, R108.1, R121.1, R134.1, U3.8 (VCC), U4.10 (~SRCLR), U4.16 (VCC), U5.10 (~SRCLR), U5.16 (VCC), U6.10 (~SRCLR), U6.16 (VCC), U7.10 (~SRCLR), U7.16 (VCC), U8.10 (~SRCLR), U8.16 (VCC), U9.10 (~SRCLR), U9.16 (VCC), U10.11 (VDD), U10.14 (~RESET), U11.11 (VDD), U11.14 (~RESET), U12.11 (VDD), U12.14 (~RESET)
/control/CAP_CHANGE.0: R108.2, U2.7 (GPIO7/TOUCH7/ADC1_CH6), U10.17 (~CHANGE)
/control/CAP_CHANGE.1: R121.2, U2.12 (GPIO8/TOUCH8/ADC1_CH7/SUBSPICS1), U11.17 (~CHANGE)
/control/CAP_CHANGE.2: R134.2, U2.17 (GPIO9/TOUCH9/ADC1_CH8/FSPIHD/SUBSPIHD), U12.17 (~CHANGE)
/control/DMX.N: J5.2, R135.1, U3.7 (B)
/control/DMX.P: J5.3, R135.2, U3.6 (A)
/control/ESP_IO13: D3.1 (K), U2.21 (GPIO13/TOUCH13/ADC2_CH2/FSPIQ/FSPIIO7/S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)
/control/ESP_IO14: TP4.1, U2.22 (GPIO14/TOUCH14/ADC2_CH3/FSPIWP/FSPIDQS/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)
/control/ESP_PROG.EN: C8.1, C10.1, J4.1, R14.2, U2.3 (EN)
/control/ESP_PROG.IO0: J4.2, U2.27 (GPIO0/BOOT)
/control/ESP_PROG.RX: J4.3, R17.2
/control/ESP_PROG.TX: J4.4, R16.2
/control/I2C.SCK: R23.2, TP9.1, U2.38 (GPIO2/TOUCH2/ADC1_CH1), U10.13 (SDA), U11.13 (SDA), U12.13 (SDA)
/control/I2C.SCL: R22.2, TP8.1, U2.39 (GPIO1/TOUCH1/ADC1_CH0), U10.16 (SCL), U11.16 (SCL), U12.16 (SCL)
/control/JTAG.TCK: R4.1, U2.32 (MTCK/GPIO39/CLK_OUT3/SUBSPICS1)
/control/JTAG.TDI: R6.1, U2.34 (MTDI/GPIO41/CLK_OUT1)
/control/JTAG.TDO: R5.1, U2.33 (MTDO/GPIO40/CLK_OUT2)
/control/JTAG.TMS: R3.1, U2.35 (MTMS/GPIO42)
/control/SR.CLOCK: TP6.1, U2.5 (GPIO5/TOUCH5/ADC1_CH4), U4.11 (SRCLK), U5.11 (SRCLK), U6.11 (SRCLK), U7.11 (SRCLK), U8.11 (SRCLK), U9.11 (SRCLK)
/control/SR.DATA: TP7.1, U2.4 (GPIO4/TOUCH4/ADC1_CH3), U5.14 (SER)
/control/SR.LATCH: TP5.1, U2.6 (GPIO6/TOUCH6/ADC1_CH5), U4.12 (RCLK), U5.12 (RCLK), U6.12 (RCLK), U7.12 (RCLK), U8.12 (RCLK), U9.12 (RCLK)
/control/USB.N: J2.A7 (D-), J2.B7 (D-), R19.2
/control/USB.P: J2.A6 (D+), J2.B6 (D+), R18.2
/control/USB_N: R19.1, U2.13 (GPIO19/U1RTS/ADC2_CH8/CLK_OUT2/USB_D-)
/control/USB_P: R18.1, U2.14 (GPIO20/U1CTS/ADC2_CH9/CLK_OUT1/USB_D+)
/display/led_row_0_1/LED_SER_OUT: U4.9 (QH'), U7.14 (SER)
/display/led_row_2_3/LED_SER_OUT: U6.9 (QH'), U9.14 (SER)
/io/USB_SHIELD_GND: J2.S1 (SHIELD), R1.2, R2.2
/power/5V_COMB: C1.1, C2.1, C3.1, D1.1 (K), Q1.2 (S), R11.2, U1.1 (VI)
GND: C1.2, C2.2, C3.2, C4.2, C5.2, C6.2, C7.2, C8.2, C9.2, C10.2, C11.2, C12.2, C13.2, C14.2, C15.2, C16.2, C17.2, C18.2, C19.2, D2.1 (K), J1.1, J2.A1 (GND), J2.A12 (GND), J2.B1 (GND), J2.B12 (GND), J3.03, J3.05, J3.07, J3.09, J5.1, Q2.2 (S), Q3.2 (S), Q4.2 (S), Q5.2 (S), Q6.2 (S), Q7.2 (S), Q8.2 (S), Q9.2 (S), Q10.2 (S), Q11.2 (S), Q12.2 (S), Q13.2 (S), Q14.2 (S), Q15.2 (S), Q16.2 (S), Q17.2 (S), Q18.2 (S), Q19.2 (S), Q20.2 (S), Q21.2 (S), Q22.2 (S), Q23.2 (S), Q24.2 (S), Q25.2 (S), Q26.2 (S), Q27.2 (S), Q28.2 (S), Q29.2 (S), Q30.2 (S), Q31.2 (S), Q32.2 (S), Q33.2 (S), Q34.2 (S), Q35.2 (S), Q36.2 (S), Q37.2 (S), R1.1, R2.1, R7.2, R8.2, R12.2, R24.2, R26.2, R28.2, R30.2, R32.2, R34.2, R36.2, R38.2, R40.2, R42.2, R44.2, R46.2, R48.2, R50.2, R52.2, R54.2, R56.2, R58.2, R60.2, R62.2, R64.2, R66.2, R68.2, R70.2, R72.2, R74.2, R76.2, R78.2, R80.2, R82.2, R84.2, R86.2, R88.2, R90.2, R92.2, R94.2, U1.2 (GND), U1.4 (GND), U2.1 (GND), U2.40 (GND), U2.41 (GND), U3.5 (GND), U4.8 (GND), U4.13 (~OE), U5.8 (GND), U5.13 (~OE), U6.8 (GND), U6.13 (~OE), U7.8 (GND), U7.13 (~OE), U8.8 (GND), U8.13 (~OE), U9.8 (GND), U9.13 (~OE), U10.10 (VSS), U10.12 (MODE), U11.10 (VSS), U11.12 (MODE), U12.10 (VSS), U12.12 (MODE)
unnamed: D2.2 (A), R13.2
unnamed: D3.2 (A), R15.2
unnamed: D4.1 (K), R25.1
unnamed: D5.1 (K), R27.1
unnamed: D6.1 (K), R29.1
unnamed: D7.1 (K), R31.1
unnamed: D8.1 (K), R33.1
unnamed: D9.1 (K), R35.1
unnamed: D10.1 (K), R37.1
unnamed: D11.1 (K), R39.1
unnamed: D12.1 (K), R41.1
unnamed: D13.1 (K), R43.1
unnamed: D14.1 (K), R45.1
unnamed: D15.1 (K), R47.1
unnamed: D16.1 (K), R49.1
unnamed: D17.1 (K), R51.1
unnamed: D18.1 (K), R53.1
unnamed: D19.1 (K), R55.1
unnamed: D20.1 (K), R57.1
unnamed: D21.1 (K), R59.1
unnamed: D22.1 (K), R61.1
unnamed: D23.1 (K), R63.1
unnamed: D24.1 (K), R65.1
unnamed: D25.1 (K), R67.1
unnamed: D26.1 (K), R69.1
unnamed: D27.1 (K), R71.1
unnamed: D28.1 (K), R73.1
unnamed: D29.1 (K), R75.1
unnamed: D30.1 (K), R77.1
unnamed: D31.1 (K), R79.1
unnamed: D32.1 (K), R81.1
unnamed: D33.1 (K), R83.1
unnamed: D34.1 (K), R85.1
unnamed: D35.1 (K), R87.1
unnamed: D36.1 (K), R89.1
unnamed: D37.1 (K), R91.1
unnamed: D38.1 (K), R93.1
unnamed: D39.1 (K), R95.1
unnamed: J2.A5 (CC1), R8.1
unnamed: J2.B5 (CC2), R7.1
unnamed: J3.02, R3.2
unnamed: J3.04, R4.2
unnamed: J3.06, R5.2
unnamed: J3.08, R6.2
unnamed: J5.4 (P3), TP1.1
unnamed: J5.5, TP2.1
unnamed: P1.1, R96.2
unnamed: P2.1, R97.2
unnamed: P3.1, R98.2
unnamed: P4.1, R99.2
unnamed: P5.1, R100.2
unnamed: P6.1, R101.2
unnamed: P7.1, R102.2
unnamed: P8.1, R103.2
unnamed: P9.1, R104.2
unnamed: P10.1, R105.2
unnamed: P11.1, R106.2
unnamed: P12.1, R107.2
unnamed: P13.1, R109.2
unnamed: P14.1, R110.2
unnamed: P15.1, R111.2
unnamed: P16.1, R112.2
unnamed: P17.1, R113.2
unnamed: P18.1, R114.2
unnamed: P19.1, R115.2
unnamed: P20.1, R116.2
unnamed: P21.1, R117.2
unnamed: P22.1, R118.2
unnamed: P23.1, R119.2
unnamed: P24.1, R120.2
unnamed: P25.1, R122.2
unnamed: P26.1, R123.2
unnamed: P27.1, R124.2
unnamed: P28.1, R125.2
unnamed: P29.1, R126.2
unnamed: P30.1, R127.2
unnamed: P31.1, R128.2
unnamed: P32.1, R129.2
unnamed: P33.1, R130.2
unnamed: P34.1, R131.2
unnamed: P35.1, R132.2
unnamed: P36.1, R133.2
unnamed: Q2.3 (D), R25.2
unnamed: Q2.1 (G), R24.1, U5.15 (QA)
unnamed: Q3.3 (D), R27.2
unnamed: Q3.1 (G), R26.1, U5.1 (QB)
unnamed: Q4.3 (D), R29.2
unnamed: Q4.1 (G), R28.1, U5.2 (QC)
unnamed: Q5.3 (D), R31.2
unnamed: Q5.1 (G), R30.1, U5.3 (QD)
unnamed: Q6.3 (D), R33.2
unnamed: Q6.1 (G), R32.1, U5.4 (QE)
unnamed: Q7.3 (D), R35.2
unnamed: Q7.1 (G), R34.1, U5.5 (QF)
unnamed: Q8.3 (D), R37.2
unnamed: Q8.1 (G), R36.1, U4.15 (QA)
unnamed: Q9.3 (D), R39.2
unnamed: Q9.1 (G), R38.1, U4.1 (QB)
unnamed: Q10.3 (D), R41.2
unnamed: Q10.1 (G), R40.1, U4.2 (QC)
unnamed: Q11.3 (D), R43.2
unnamed: Q11.1 (G), R42.1, U4.3 (QD)
unnamed: Q12.3 (D), R45.2
unnamed: Q12.1 (G), R44.1, U4.4 (QE)
unnamed: Q13.3 (D), R47.2
unnamed: Q13.1 (G), R46.1, U4.5 (QF)
unnamed: Q14.3 (D), R49.2
unnamed: Q14.1 (G), R48.1, U7.15 (QA)
unnamed: Q15.3 (D), R51.2
unnamed: Q15.1 (G), R50.1, U7.1 (QB)
unnamed: Q16.3 (D), R53.2
unnamed: Q16.1 (G), R52.1, U7.2 (QC)
unnamed: Q17.3 (D), R55.2
unnamed: Q17.1 (G), R54.1, U7.3 (QD)
unnamed: Q18.3 (D), R57.2
unnamed: Q18.1 (G), R56.1, U7.4 (QE)
unnamed: Q19.3 (D), R59.2
unnamed: Q19.1 (G), R58.1, U7.5 (QF)
unnamed: Q20.3 (D), R61.2
unnamed: Q20.1 (G), R60.1, U6.15 (QA)
unnamed: Q21.3 (D), R63.2
unnamed: Q21.1 (G), R62.1, U6.1 (QB)
unnamed: Q22.3 (D), R65.2
unnamed: Q22.1 (G), R64.1, U6.2 (QC)
unnamed: Q23.3 (D), R67.2
unnamed: Q23.1 (G), R66.1, U6.3 (QD)
unnamed: Q24.3 (D), R69.2
unnamed: Q24.1 (G), R68.1, U6.4 (QE)
unnamed: Q25.3 (D), R71.2
unnamed: Q25.1 (G), R70.1, U6.5 (QF)
unnamed: Q26.3 (D), R73.2
unnamed: Q26.1 (G), R72.1, U9.15 (QA)
unnamed: Q27.3 (D), R75.2
unnamed: Q27.1 (G), R74.1, U9.1 (QB)
unnamed: Q28.3 (D), R77.2
unnamed: Q28.1 (G), R76.1, U9.2 (QC)
unnamed: Q29.3 (D), R79.2
unnamed: Q29.1 (G), R78.1, U9.3 (QD)
unnamed: Q30.3 (D), R81.2
unnamed: Q30.1 (G), R80.1, U9.4 (QE)
unnamed: Q31.3 (D), R83.2
unnamed: Q31.1 (G), R82.1, U9.5 (QF)
unnamed: Q32.3 (D), R85.2
unnamed: Q32.1 (G), R84.1, U8.15 (QA)
unnamed: Q33.3 (D), R87.2
unnamed: Q33.1 (G), R86.1, U8.1 (QB)
unnamed: Q34.3 (D), R89.2
unnamed: Q34.1 (G), R88.1, U8.2 (QC)
unnamed: Q35.3 (D), R91.2
unnamed: Q35.1 (G), R90.1, U8.3 (QD)
unnamed: Q36.3 (D), R93.2
unnamed: Q36.1 (G), R92.1, U8.4 (QE)
unnamed: Q37.3 (D), R95.2
unnamed: Q37.1 (G), R94.1, U8.5 (QF)
unnamed: R20.1, U2.10 (GPIO17/U1TXD/ADC2_CH6)
unnamed: R21.1, U2.11 (GPIO18/U1RXD/ADC2_CH7/CLK_OUT3)
unnamed: U2.23 (GPIO21), U3.3 (DE), U3.4 (DI)
unnamed: R17.1, U2.36 (U0RXD/GPIO44/CLK_OUT2)
unnamed: R16.1, U2.37 (U0TXD/GPIO43/CLK_OUT1)
unnamed: R20.2, U3.1 (RO)
unnamed: R21.2, U3.2 (~RE)
unnamed: U4.14 (SER), U5.9 (QH')
unnamed: U6.14 (SER), U7.9 (QH')
unnamed: U8.14 (SER), U9.9 (QH')
unnamed: R107.1, U10.9 (KEY0)
unnamed: R106.1, U10.8 (KEY1)
unnamed: R105.1, U10.7 (KEY2/GPO0)
unnamed: R104.1, U10.6 (KEY3/GPO1)
unnamed: R103.1, U10.5 (KEY4/GPO2)
unnamed: R102.1, U10.4 (KEY5/GPO3)
unnamed: R101.1, U10.3 (KEY6/GPO4)
unnamed: R100.1, U10.2 (KEY7/GPO5)
unnamed: R99.1, U10.1 (KEY8/GPO6)
unnamed: R98.1, U10.20 (KEY9/GPO7)
unnamed: R97.1, U10.19 (KEY10/GPO8)
unnamed: R96.1, U10.18 (KEY11/GPO9)
unnamed: R120.1, U11.9 (KEY0)
unnamed: R119.1, U11.8 (KEY1)
unnamed: R118.1, U11.7 (KEY2/GPO0)
unnamed: R117.1, U11.6 (KEY3/GPO1)
unnamed: R116.1, U11.5 (KEY4/GPO2)
unnamed: R115.1, U11.4 (KEY5/GPO3)
unnamed: R114.1, U11.3 (KEY6/GPO4)
unnamed: R113.1, U11.2 (KEY7/GPO5)
unnamed: R112.1, U11.1 (KEY8/GPO6)
unnamed: R111.1, U11.20 (KEY9/GPO7)
unnamed: R110.1, U11.19 (KEY10/GPO8)
unnamed: R109.1, U11.18 (KEY11/GPO9)
unnamed: R133.1, U12.9 (KEY0)
unnamed: R132.1, U12.8 (KEY1)
unnamed: R131.1, U12.7 (KEY2/GPO0)
unnamed: R130.1, U12.6 (KEY3/GPO1)
unnamed: R129.1, U12.5 (KEY4/GPO2)
unnamed: R128.1, U12.4 (KEY5/GPO3)
unnamed: R127.1, U12.3 (KEY6/GPO4)
unnamed: R126.1, U12.2 (KEY7/GPO5)
unnamed: R125.1, U12.1 (KEY8/GPO6)
unnamed: R124.1, U12.20 (KEY9/GPO7)
unnamed: R123.1, U12.19 (KEY10/GPO8)
unnamed: R122.1, U12.18 (KEY11/GPO9)
VBUS: D1.2 (A), J2.A4 (VBUS), J2.A9 (VBUS), J2.B4 (VBUS), J2.B9 (VBUS), Q1.1 (G), R12.1

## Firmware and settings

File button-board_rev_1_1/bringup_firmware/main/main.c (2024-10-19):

#include "freertos/FreeRTOS.h"
#include "freertos/task.h"

#include "driver/gpio.h"
#include "driver/i2c.h"
#include "esp_app_trace.h"
#include "esp_log.h"
#include "nvs_flash.h"

#include "esp_dmx.h"

#define LED_SR_DATA (GPIO_NUM_4)
#define LED_SR_CLOCK (GPIO_NUM_5)
#define LED_SR_LATCH (GPIO_NUM_6)
#define LED_SR_ALL_ON (0x003F3F3F)
#define LED_SR_ALL_OFF (0x00000000)

#define I2C_SCL_1 (GPIO_NUM_1)
#define I2C_SDA_1 (GPIO_NUM_2)
#define I2C_SCL_2 (GPIO_NUM_9)
#define I2C_SDA_2 (GPIO_NUM_10)
#define I2C_EXPECT_ACK (true)
#define AT42QT_I2C_ADDR (0x1C)

#define CAP_TOUCH_CHANGE_0 (GPIO_NUM_7)
#define CAP_TOUCH_CHANGE_1 (GPIO_NUM_8)

#define DMX_TX_PIN (GPIO_NUM_21)
#define DMX_RX_PIN (GPIO_NUM_17)
#define DMX_DE_nRE_PIN (GPIO_NUM_18)

#define TAG "main"

typedef struct {
    uint8_t master_dim;
    uint8_t r;
    uint8_t g;
    uint8_t b;
    uint8_t w;
    uint8_t strobe;
    uint8_t mode;   // 0-250 Auto mode, 251-255 sound mode
    uint8_t speed;  // 0-250 control speed for mode
} par_dmx_packet_t;

static volatile bool    cap_touch_change_flag;
static volatile uint8_t cap_touch_change_mask;

static void IRAM_ATTR cap_touch_change_isr(void *arg) {
    uint32_t pin = (uint32_t)arg;
    configASSERT(pin == CAP_TOUCH_CHANGE_0 || pin == CAP_TOUCH_CHANGE_1);

    cap_touch_change_flag = true;
    cap_touch_change_mask |= pin;
}

static uint32_t key_status_to_led_mask(uint32_t key_status) {
    uint32_t mask = 0;

    // First 12 bits are cap touch 0, mapped differently than cap touch 1
    for (uint8_t i = 0; i < 12; i++) {
        if (key_status & (1 << i)) {
            mask |= (1 << (13 - i - 2 * (i / 6)));
        }
    }

    // Pull off top 6 bits and shift down to normal byte
    uint8_t cap_touch_1 = (key_status >> 12) & 0xFF;
    for (uint8_t i = 0; i < 8; i++) {
        if (cap_touch_1 & (1 << i)) {
            mask |= (1 << (21 - i));
        }
    }

    return mask;
}

static void led_sr_send(uint32_t mask) {
    gpio_set_level(LED_SR_CLOCK, 0);
    for (uint8_t i = 0; i < 24; i++) {
        gpio_set_level(LED_SR_DATA, (1 << (24 - i - 1) & mask));
        vTaskDelay(pdMS_TO_TICKS(1));
        gpio_set_level(LED_SR_CLOCK, 1);
        vTaskDelay(pdMS_TO_TICKS(1));
        gpio_set_level(LED_SR_CLOCK, 0);
        vTaskDelay(pdMS_TO_TICKS(1));
    }

    vTaskDelay(pdMS_TO_TICKS(1));
    gpio_set_level(LED_SR_LATCH, 1);
    vTaskDelay(pdMS_TO_TICKS(1));
    gpio_set_level(LED_SR_LATCH, 0);
}

static uint16_t cap_touch_0_read_status_bytes() {
    i2c_cmd_handle_t i2c_cmd_handle = {0};
    uint8_t          key_status_0   = 0x00;
    uint8_t          key_status_1   = 0x00;
    uint8_t          detect_status  = 0x00;

    // Write internal register addr of key status byte 2 with write bit
    // Build command within cmd handle - nothing is transmitted at this point
    i2c_cmd_handle = i2c_cmd_link_create();
    i2c_master_start(i2c_cmd_handle);
    i2c_master_write_byte(i2c_cmd_handle, (AT42QT_I2C_ADDR << 1) | I2C_MASTER_WRITE,
                          I2C_EXPECT_ACK);                        // addr+wr
    i2c_master_write_byte(i2c_cmd_handle, 0x03, I2C_EXPECT_ACK);  // mem_addr in slave
    i2c_master_stop(i2c_cmd_handle);

    // Transmit constructed cmd sequence
    i2c_master_cmd_begin(I2C_NUM_0, i2c_cmd_handle, pdMS_TO_TICKS(10));

    // Tear down constructed cmd handle for that specific cmd
    i2c_cmd_link_delete(i2c_cmd_handle);

    // Read internal register of key status 0 with read bit
    i2c_cmd_handle = i2c_cmd_link_create();
    i2c_master_start(i2c_cmd_handle);
    i2c_master_write_byte(i2c_cmd_handle, (AT42QT_I2C_ADDR << 1) | I2C_MASTER_READ, I2C_EXPECT_ACK);  // addr+re
    i2c_master_read_byte(i2c_cmd_handle, &key_status_0, I2C_MASTER_LAST_NACK);
    i2c_master_stop(i2c_cmd_handle);
    i2c_master_cmd_begin(I2C_NUM_0, i2c_cmd_handle, pdMS_TO_TICKS(10));
    i2c_cmd_link_delete(i2c_cmd_handle);

    // Write internal register addr of key status byte 1 with write bit
    i2c_cmd_handle = i2c_cmd_link_create();
    i2c_master_start(i2c_cmd_handle);
    i2c_master_write_byte(i2c_cmd_handle, (AT42QT_I2C_ADDR << 1) | I2C_MASTER_WRITE,
                          I2C_EXPECT_ACK);                        // addr+wr
    i2c_master_write_byte(i2c_cmd_handle, 0x04, I2C_EXPECT_ACK);  // mem_addr in slave
    i2c_master_stop(i2c_cmd_handle);
    i2c_master_cmd_begin(I2C_NUM_0, i2c_cmd_handle, pdMS_TO_TICKS(10));
    i2c_cmd_link_delete(i2c_cmd_handle);

    // Read internal register of key status 1 with read bit
    i2c_cmd_handle = i2c_cmd_link_create();
    i2c_master_start(i2c_cmd_handle);
    i2c_master_write_byte(i2c_cmd_handle, (AT42QT_I2C_ADDR << 1) | I2C_MASTER_READ, I2C_EXPECT_ACK);  // addr+re
    i2c_master_read_byte(i2c_cmd_handle, &key_status_1, I2C_MASTER_LAST_NACK);
    i2c_master_stop(i2c_cmd_handle);
    i2c_master_cmd_begin(I2C_NUM_0, i2c_cmd_handle, pdMS_TO_TICKS(10));
    i2c_cmd_link_delete(i2c_cmd_handle);

    // Write internal register addr of detection status with write bit
    i2c_cmd_handle = i2c_cmd_link_create();
    i2c_master_start(i2c_cmd_handle);
    i2c_master_write_byte(i2c_cmd_handle, (AT42QT_I2C_ADDR << 1) | I2C_MASTER_WRITE,
                          I2C_EXPECT_ACK);                        // addr+wr
    i2c_master_write_byte(i2c_cmd_handle, 0x02, I2C_EXPECT_ACK);  // mem_addr in slave
    i2c_master_stop(i2c_cmd_handle);
    i2c_master_cmd_begin(I2C_NUM_0, i2c_cmd_handle, pdMS_TO_TICKS(10));
    i2c_cmd_link_delete(i2c_cmd_handle);

    // Read internal register of detection status with read bit
    i2c_cmd_handle = i2c_cmd_link_create();
    i2c_master_start(i2c_cmd_handle);
    i2c_master_write_byte(i2c_cmd_handle, (AT42QT_I2C_ADDR << 1) | I2C_MASTER_READ, I2C_EXPECT_ACK);  // addr+re
    i2c_master_read_byte(i2c_cmd_handle, &detect_status, I2C_MASTER_LAST_NACK);
    i2c_master_stop(i2c_cmd_handle);
    i2c_master_cmd_begin(I2C_NUM_0, i2c_cmd_handle, pdMS_TO_TICKS(10));
    i2c_cmd_link_delete(i2c_cmd_handle);

    // ESP_LOGI(TAG,
    //          "cap touch 0 (0xK11|..|K0): 0x%03X, Detect status: 0x%02X",
    //          (key_status_1 << 8) | key_status_0,
    //          detect_status);
    return (key_status_1 << 8) | key_status_0;
}

static uint8_t cap_touch_1_read_status_bytes() {
    i2c_cmd_handle_t i2c_cmd_handle = {0};
    uint8_t          key_status_0   = 0x00;
    uint8_t          key_status_1   = 0x00;
    uint8_t          detect_status  = 0x00;

    // key status byte 1
    i2c_cmd_handle = i2c_cmd_link_create();
    i2c_master_start(i2c_cmd_handle);
    i2c_master_write_byte(i2c_cmd_handle, (AT42QT_I2C_ADDR << 1) | I2C_MASTER_WRITE,
                          I2C_EXPECT_ACK);                        // addr+wr
    i2c_master_write_byte(i2c_cmd_handle, 0x03, I2C_EXPECT_ACK);  // mem_addr in slave
    i2c_master_stop(i2c_cmd_handle);
    i2c_master_cmd_begin(I2C_NUM_1, i2c_cmd_handle, pdMS_TO_TICKS(10));
    i2c_cmd_link_delete(i2c_cmd_handle);
    i2c_cmd_handle = i2c_cmd_link_create();
    i2c_master_start(i2c_cmd_handle);
    i2c_master_write_byte(i2c_cmd_handle, (AT42QT_I2C_ADDR << 1) | I2C_MASTER_READ, I2C_EXPECT_ACK);  // addr+re
    i2c_master_read_byte(i2c_cmd_handle, &key_status_0, I2C_MASTER_LAST_NACK);
    i2c_master_stop(i2c_cmd_handle);
    i2c_master_cmd_begin(I2C_NUM_1, i2c_cmd_handle, pdMS_TO_TICKS(10));
    i2c_cmd_link_delete(i2c_cmd_handle);

    // key status byte 2
    i2c_cmd_handle = i2c_cmd_link_create();
    i2c_master_start(i2c_cmd_handle);
    i2c_master_write_byte(i2c_cmd_handle, (AT42QT_I2C_ADDR << 1) | I2C_MASTER_WRITE,
                          I2C_EXPECT_ACK);                        // addr+wr
    i2c_master_write_byte(i2c_cmd_handle, 0x04, I2C_EXPECT_ACK);  // mem_addr in slave
    i2c_master_stop(i2c_cmd_handle);
    i2c_master_cmd_begin(I2C_NUM_1, i2c_cmd_handle, pdMS_TO_TICKS(10));
    i2c_cmd_link_delete(i2c_cmd_handle);
    i2c_cmd_handle = i2c_cmd_link_create();
    i2c_master_start(i2c_cmd_handle);
    i2c_master_write_byte(i2c_cmd_handle, (AT42QT_I2C_ADDR << 1) | I2C_MASTER_READ, I2C_EXPECT_ACK);  // addr+re
    i2c_master_read_byte(i2c_cmd_handle, &key_status_1, I2C_MASTER_LAST_NACK);
    i2c_master_stop(i2c_cmd_handle);
    i2c_master_cmd_begin(I2C_NUM_1, i2c_cmd_handle, pdMS_TO_TICKS(10));
    i2c_cmd_link_delete(i2c_cmd_handle);

    // detection status byte
    i2c_cmd_handle = i2c_cmd_link_create();
    i2c_master_start(i2c_cmd_handle);
    i2c_master_write_byte(i2c_cmd_handle, (AT42QT_I2C_ADDR << 1) | I2C_MASTER_WRITE,
                          I2C_EXPECT_ACK);                        // addr+wr
    i2c_master_write_byte(i2c_cmd_handle, 0x02, I2C_EXPECT_ACK);  // mem_addr in slave
    i2c_master_stop(i2c_cmd_handle);
    i2c_master_cmd_begin(I2C_NUM_1, i2c_cmd_handle, pdMS_TO_TICKS(10));
    i2c_cmd_link_delete(i2c_cmd_handle);
    i2c_cmd_handle = i2c_cmd_link_create();
    i2c_master_start(i2c_cmd_handle);
    i2c_master_write_byte(i2c_cmd_handle, (AT42QT_I2C_ADDR << 1) | I2C_MASTER_READ, I2C_EXPECT_ACK);  // addr+re
    i2c_master_read_byte(i2c_cmd_handle, &detect_status, I2C_MASTER_LAST_NACK);
    i2c_master_stop(i2c_cmd_handle);
    i2c_master_cmd_begin(I2C_NUM_1, i2c_cmd_handle, pdMS_TO_TICKS(10));
    i2c_cmd_link_delete(i2c_cmd_handle);

    uint8_t key_status = ((key_status_0 & 0xC0) >> 6) | (key_status_1 << 2);
    // ESP_LOGI(TAG, "cap touch 1 (0xK11|..|K0): 0x%02X, Detect status: 0x%02X", key_status, detect_status);
    return key_status;
}

static void system_init(void) {
    esp_err_t ret = nvs_flash_init();

    if (ret == ESP_ERR_NVS_NO_FREE_PAGES || ret == ESP_ERR_NVS_NEW_VERSION_FOUND) {
        ESP_ERROR_CHECK(nvs_flash_erase());
        ret = nvs_flash_init();
    }

    ESP_ERROR_CHECK(ret);
}

static void system_start(void) {
}

static void app_init() {
    cap_touch_change_flag = false;
    cap_touch_change_mask = 0x00;

    gpio_config_t output_config = {
        .pin_bit_mask = (1ULL << LED_SR_DATA) | (1ULL << LED_SR_CLOCK) | (1ULL << LED_SR_LATCH),
        .intr_type    = GPIO_INTR_DISABLE,
        .mode         = GPIO_MODE_OUTPUT,
        .pull_up_en   = false,
        .pull_down_en = false,
    };
    ESP_ERROR_CHECK(gpio_config(&output_config));

    gpio_config_t input_interrupt_config = {
        .pin_bit_mask = (1ULL << CAP_TOUCH_CHANGE_0) | (1ULL << CAP_TOUCH_CHANGE_1),
        .intr_type    = GPIO_INTR_NEGEDGE,
        .mode         = GPIO_MODE_INPUT,
        .pull_up_en   = false,  // pulled up externally
        .pull_down_en = false,
    };
    ESP_ERROR_CHECK(gpio_config(&input_interrupt_config));
    gpio_install_isr_service(0x0);
    gpio_isr_handler_add(CAP_TOUCH_CHANGE_0, cap_touch_change_isr, (void *)CAP_TOUCH_CHANGE_0);
    gpio_isr_handler_add(CAP_TOUCH_CHANGE_1, cap_touch_change_isr, (void *)CAP_TOUCH_CHANGE_1);

    i2c_config_t i2c_config = {
        .mode             = I2C_MODE_MASTER,
        .sda_io_num       = I2C_SDA_1,
        .sda_pullup_en    = GPIO_PULLUP_DISABLE,
        .scl_io_num       = I2C_SCL_1,
        .scl_pullup_en    = GPIO_PULLUP_DISABLE,
        .master.clk_speed = 100000,
        .clk_flags        = 0,
    };

    ESP_ERROR_CHECK(i2c_param_config(I2C_NUM_0, &i2c_config));
    ESP_ERROR_CHECK(i2c_driver_install(I2C_NUM_0, I2C_MODE_MASTER, 0, 0, 0));

    i2c_config.sda_io_num    = I2C_SDA_2;
    i2c_config.scl_io_num    = I2C_SCL_2;
    i2c_config.sda_pullup_en = GPIO_PULLUP_ENABLE;
    i2c_config.scl_pullup_en = GPIO_PULLUP_ENABLE;
    ESP_ERROR_CHECK(i2c_param_config(I2C_NUM_1, &i2c_config));
    ESP_ERROR_CHECK(i2c_driver_install(I2C_NUM_1, I2C_MODE_MASTER, 0, 0, 0));

    const int         personality_count = 1;
    dmx_personality_t personalities[]   = {{1, "Default Personality"}};

    const dmx_port_t dmx_num = DMX_NUM_1;
    dmx_config_t     config  = DMX_CONFIG_DEFAULT;
    dmx_driver_install(dmx_num, &config, personalities, personality_count);
    dmx_set_pin(dmx_num, DMX_TX_PIN, DMX_RX_PIN, DMX_DE_nRE_PIN);
}

static void app_start(void) {
}

void app_main(void) {
    ESP_LOGI(TAG, "Starting cap-touch-button-board firmware");

    esp_log_level_set(TAG, ESP_LOG_DEBUG);

    system_init();
    system_start();

    app_init();
    app_start();

    // LED init flashes
    uint32_t mask    = 0x000000;
    uint8_t  bit_pos = 0;
    uint8_t  i       = 0;
    while (i < 3) {
        mask = (1 << bit_pos);
        led_sr_send(mask);

        bit_pos++;
        if (bit_pos == 6) {
            bit_pos = 8;
        } else if (bit_pos == 14) {
            bit_pos = 16;
        } else if (bit_pos >= 22) {
            bit_pos = 0;
            i++;
        }

        vTaskDelay(pdMS_TO_TICKS(50));
    }

    mask = LED_SR_ALL_ON;
    led_sr_send(mask);
    vTaskDelay(pdMS_TO_TICKS(1000));
    mask = LED_SR_ALL_OFF;
    led_sr_send(mask);
    mask = 1;

    cap_touch_0_read_status_bytes();
    cap_touch_1_read_status_bytes();

    uint32_t         key_status                 = 0x0000;
    par_dmx_packet_t current_packet             = {0};
    uint8_t          start_byte                 = 0x00;
    uint8_t          par_mask                   = 0x00;
    uint8_t          last_par_mask              = 0x00;
    uint8_t          key_status_bottom_row      = 0x00;
    uint8_t          last_key_status_bottom_row = 0x00;
    while (1) {
        if (cap_touch_change_flag) {
            cap_touch_change_flag = false;
            key_status            = 0;

            if (cap_touch_change_mask | CAP_TOUCH_CHANGE_0) {
                cap_touch_change_mask &= ~CAP_TOUCH_CHANGE_0;
                key_status |= cap_touch_0_read_status_bytes();
            }

            if (cap_touch_change_mask | CAP_TOUCH_CHANGE_1) {
                cap_touch_change_mask &= ~CAP_TOUCH_CHANGE_1;
                uint8_t temp = cap_touch_1_read_status_bytes();
                key_status |= (temp << 12);
            }

            // Hack around shorted led <-> cap touch pad triggering constantly. If this is the only change after we're
            // triggered, ignore and continue
            if (key_status == (1 << 2) || key_status == ((1 << 2) | (1 << 1))) {
                continue;
            }

            mask = key_status_to_led_mask(key_status);
            led_sr_send(mask);
        }

        key_status_bottom_row = (key_status >> 6) & 0xFF;
        if (key_status_bottom_row == 0) {
            par_mask = last_par_mask;
        } else {
            ESP_LOGI(TAG, "this: 0x%02X - last: 0x%02X", key_status_bottom_row, last_key_status_bottom_row);
            last_key_status_bottom_row &= key_status_bottom_row;
            key_status_bottom_row ^= last_key_status_bottom_row;
            if (key_status_bottom_row == 0) {
                par_mask = last_par_mask;
            } else {
                switch (key_status_bottom_row) {
                    case 1 << 0:
                        par_mask = 0xFF;
                        break;
                    case 1 << 1:
                        par_mask = (0xFF / 5) * 4;
                        break;
                    case 1 << 2:
                        par_mask = (0xFF / 5) * 3;
                        break;
                    case 1 << 3:
                        par_mask = (0xFF / 5) * 2;
                        break;
                    case 1 << 4:
                        par_mask = 0xFF / 5;
                        break;
                    case 1 << 5:
                        par_mask = 0x00;
                        break;
                    default:
                        // Means two bits have been enabled since the last loop
                        ESP_LOGI(TAG, "Unhandled bottom row val: 0x%02X", key_status_bottom_row);
                        break;
                }
            }
        }

        last_key_status_bottom_row = key_status_bottom_row;

        current_packet.master_dim = par_mask;
        current_packet.r          = 0xFF;
        current_packet.g          = 0xFF;
        current_packet.b          = 0xFF;
        current_packet.w          = 0xFF;
        current_packet.strobe     = 0;
        current_packet.mode       = 0;
        current_packet.speed      = 0;

        dmx_write(DMX_NUM_1, &start_byte, 1);
        dmx_write_offset(DMX_NUM_1, 0x01, &current_packet, sizeof(par_dmx_packet_t));
        dmx_send(DMX_NUM_1);

        last_par_mask = par_mask;

        /*
        // Test DMX output sending RGB sequence
        switch (color) {
            case 0:
                r     = 0xFF;
                b     = 0x00;
                g     = 0x00;
                color = 1;
                break;
            case 1:
                r     = 0x00;
                b     = 0xFF;
                g     = 0x00;
                color = 2;
                break;
            case 2:
                r     = 0x00;
                b     = 0x00;
                g     = 0xFF;
                color = 0;
                break;
            default:
                configASSERT(0);
        }

        for (uint16_t i = 0; i < 510; i += 3) {
            dmx_buffer[i]     = r;
            dmx_buffer[i + 1] = g;
            dmx_buffer[i + 2] = b;
        }

        dmx_write(DMX_NUM_1, &start_addr, 1);
        dmx_write_offset(DMX_NUM_1, 0x1, dmx_buffer, sizeof(dmx_buffer));
        dmx_send(DMX_NUM_1);
        vTaskDelay(pdMS_TO_TICKS(50));
        */
    }
}

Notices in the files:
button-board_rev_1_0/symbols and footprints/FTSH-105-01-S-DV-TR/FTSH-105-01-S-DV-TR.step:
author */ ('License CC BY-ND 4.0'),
